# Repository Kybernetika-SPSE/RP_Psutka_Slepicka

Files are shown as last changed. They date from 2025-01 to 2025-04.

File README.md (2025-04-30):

# Dílčí vypracovnání
[here](škola_info)
---

# 🛰️ Lokalizační systém na dvoupásovém vozidle pomocí ESP32, UWB a Wi-Fi

Tato ročníková práce představuje hybridní lokalizační systém postavený na platformě ESP32, který je integrován do dvoupásového robotického vozidla. Systém využívá **Ultra-Wideband (UWB)** pro přesné měření vzdáleností a **Wi-Fi fingerprinting** pro přibližnou lokalizaci. ESP32 zároveň umožňuje řízení vozidla nebo může fungovat jako samostatný **navigační modul** připojený přes Serial k jinému mikrokontroléru.

## ⚙️ Hlavní funkce

- 🚗 **Mobilní platforma:** ESP32 je umístěno na dvoupásovém vozidle a může jej samostatně ovládat.
- 🔁 **Modulární režim:** ESP32 lze přepnout do režimu **navigačního modulu** a komunikovat s jiným mikrokontrolérem přes sériovou linku.
- 📡 **UWB lokalizace:** Využívá se knihovna [`thotro/arduino-dw1000`](https://github.com/thotro/arduino-dw1000) pro přesné měření vzdáleností.
- 📶 **Wi-Fi fingerprinting:** ESP32 detekuje okolní Wi-Fi sítě a odhaduje polohu v neznámém prostředí.
- 🌐 **Webové rozhraní:** ESP32 hostuje jednoduchý web s informacemi o aktuální poloze.
- 🐍 **Python vizualizace:** V reálném čase je možné zobrazit pozici vozidla pomocí animace v Pythonu (`matplotlib`).
- 🔌 **Serial komunikace:** ESP32 odesílá výstupy polohy přes Serial — buď do počítače, nebo do jiného MCU.

## 📁 Struktura projektu

```
RP_Psutka_Slepicka/
├── PCB/                     # KiCad soubory pro návrh desky plošných spojů
├── modely/                  # 3D modely pro tisk
├── škola_info/              # Dílčí vypracování
├── docs/                    # Fotodokumentace
├── src/
│   ├── main/
│   │   ├── data/
│   │   │   ├── *.html       # Webové stránky hostované ESP32
│   │   │   └── *.json       # Hesla k Wi-Fi, uložené Wi-Fi fingerprinty
│   │   └── src/             # Zdrojový kód pro hlavní firmware ESP32
│   └── wifi-scan/           # ESP32 projekt pro sběr Wi-Fi fingerprintů
```

## 🧰 Použité technologie

- **ESP32-DevKitC v4**
- **DWM1000 UWB moduly**
- **PlatformIO + Arduino framework**
- **Python + matplotlib**
- **HTML + JavaScript (web na ESP32)**

## 🔧 Režimy provozu

### 🚘 Autonomní režim
ESP32 ovládá motorové jednotky vozidla a využívá lokalizaci pro navigaci.

### 🔗 Navigační modul
ESP32 funguje jako lokalizační jednotka připojená k jinému mikrokontroléru (např. další ESP32 nebo Arduino). Odhadovaná pozice je pravidelně posílána přes Serial.

## 💬 Komunikace po Serialu

Formát výstupu:
```
POS:[x,y] (2D) nebo POS:[x,y,z] (3D)
```

Možné rozšíření o příkazy pro změnu režimu, kalibraci, atd.

## 📸 Ukázky

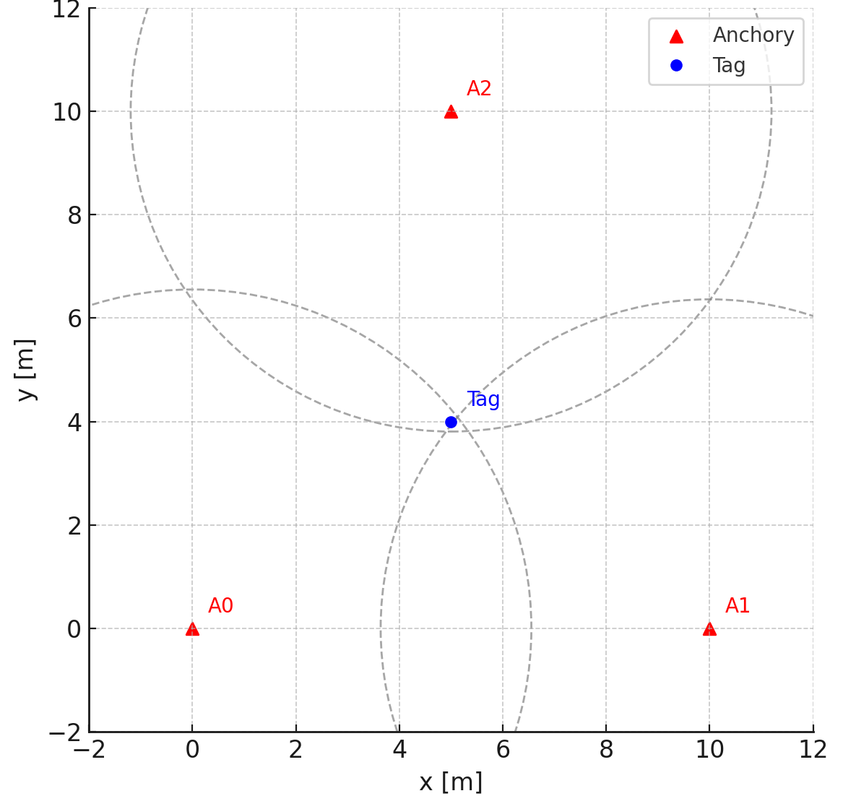
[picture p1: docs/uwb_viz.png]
UWB simulace


## 📚 Zdroje

- [DW1000 datasheet](https://thetoolchain.com/mirror/dw1000/dw1000_user_manual_v2.05.pdf)
- [UWB localization – Wikipedia](https://en.wikipedia.org/wiki/Real-time_locating_system)
- [Arduino-DW1000 GitHub repo](https://github.com/thotro/arduino-dw1000)

## 📄 Licence

Projekt je vytvořen jako ročníková práce a není určen pro komerční použití.

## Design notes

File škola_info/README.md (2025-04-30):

# Dílčí vypracovnání

## Psutka
[zadání](RP_Zadání_Psutka.pdf)

[dokumentace](docs/Psutka/)

+ [Prosinec](reporty/Psutka/2024_12_20.pdf)
+ [Leden](reporty/Psutka/2025_1_31.pdf)
+ [Únor](reporty/Psutka/2025_2_28.pdf)
+ [Březen](reporty/Psutka/2025_3_28.pdf)

## Slepička
[zadání](RP_Zadání_Slepička.pdf)

[dokumentace](docs/Slepička/)

+ [Prosinec](reporty/Slepička/2024_12_20.pdf)
+ [Leden](reporty/Slepička/2025_1_31.pdf)
+ [Únor](reporty/Slepička/2025_2_28.pdf)
+ [Březen](reporty/Slepička/2025_3_28.pdf)

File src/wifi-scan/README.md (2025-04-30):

# Funkce wifi-scan

Tento projekt poskytuje nástroje pro skenování dostupných WiFi sítí pomocí ESP32 a jejich následné zpracování.

## Použití

1. Připojte ESP32 k počítači.
2. Spusťte `scan.py` pro inicializaci skenování.
3. Zadejte název a lokaci pro každé skenování.
4. Data budou uložena do `scanData/networks_raw.json`.
5. Spusťte `format.py` pro formátování dat do `scanData/networks.json`.

## Struktura souborů

- `scan.py`: Skript pro skenování WiFi sítí a ukládání dat.
- `format.py`: Skript pro formátování naskenovaných dat.
- `scanData/`: Složka obsahující naskenovaná data.
- `src/`: Zdrojové kódy pro ESP32.

## Poznámky

- Tento projekt vyžaduje knihovnu `pyserial` pro komunikaci s ESP32. Nainstalujte ji pomocí `pip install pyserial`.
- Ujistěte se, že ESP32 má potřebná oprávnění pro přístup k sériovému portu.
- Pravidelně zálohujte data skenování, abyste předešli jejich ztrátě.

Pro více informací se odkažte na hlavní dokumentaci projektu.

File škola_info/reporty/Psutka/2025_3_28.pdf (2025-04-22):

# RP report

Matěj Psutka

28.3.2025

Během tohoto měsíce jsem dokoupil všechny zbývající součástky potřebné k dokončení projektu. Některé z nich již dorazily, zatímco zbytek očekávám v průběhu příštího týdne. Jakmile budou všechny komponenty k dispozici, začne proces pájení a sestavování celého systému.

Zakoupené součástky:

- Spínače
- 3x Baterie 3.7V
- Balancer na baterie
- Socket na 3 baterie
- Nabíjecí modul 12.5V
- H-můstek 5A 3-14V
- Stepdown modul 6-32V na 5V
- 2x N20 Mini micro metal gear motor 6V 500RPM
- 2x Pogo 2pin
- 2x Pogo 4pin
- 4x Pogo 5pin

Některé z našich webových stránek jsem některé z nich lehce poupravil. CSS styl jsem přepsal do vlastního souboru který se dá jednoduše upravovat, což zjednodušuje tvorbu stránek.

Začal jsem se učit s knihovnou Pygame s cílem vytvořit přehledné grafické prostředí pro ovládání Auta. V tuto chvíli se pouze zaměřuji na základy.

1

Také jsem vytvořil schéma zapojení elektroniky pro autíčko. Toto schéma slouží jako základ pro propojení jednotlivých komponent a usnadní sestavení celého systému.

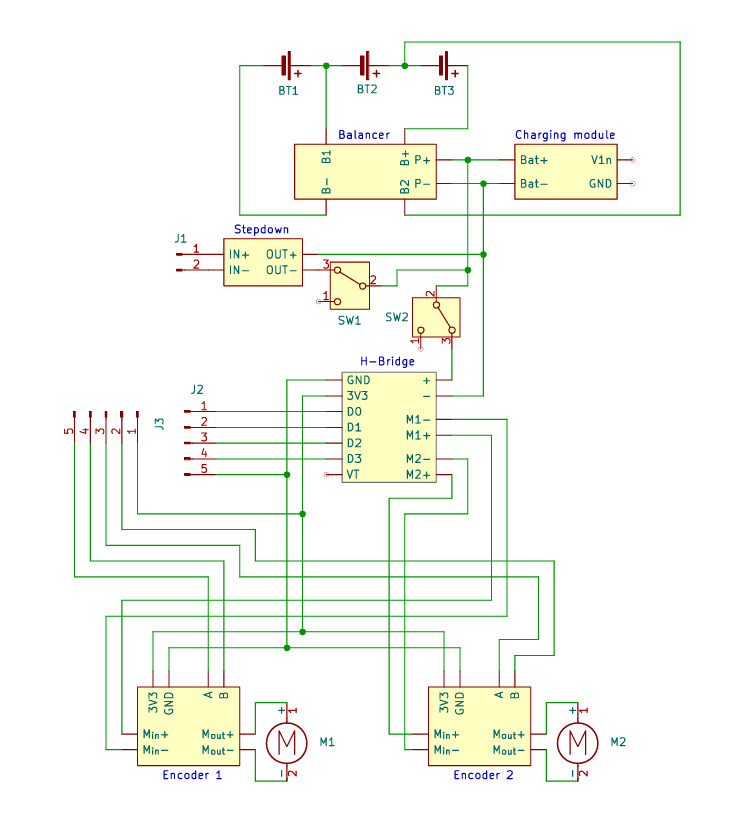
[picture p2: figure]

2

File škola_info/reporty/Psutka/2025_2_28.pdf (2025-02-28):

# RP report

Matěj Psutka

28.2.2025

Tenhle měsíc jsem dodělal finální verze modelu krabičky na čip s vývody na 3 LED a několik děr na pogo piny které se nakonec magneticky připojí ke zbytku auta. Plán je že máme malou krabičku ve které bude většina komponentů a půjde nastavit jedním tlačítkem zda se bude chovat jako maják a nebo jako auto. V případě majáku tak postačí a u auta tak se tato malá krabička připojí pomocí magnetů k větší krabičce ve které budou motory a celý zbytek auta.

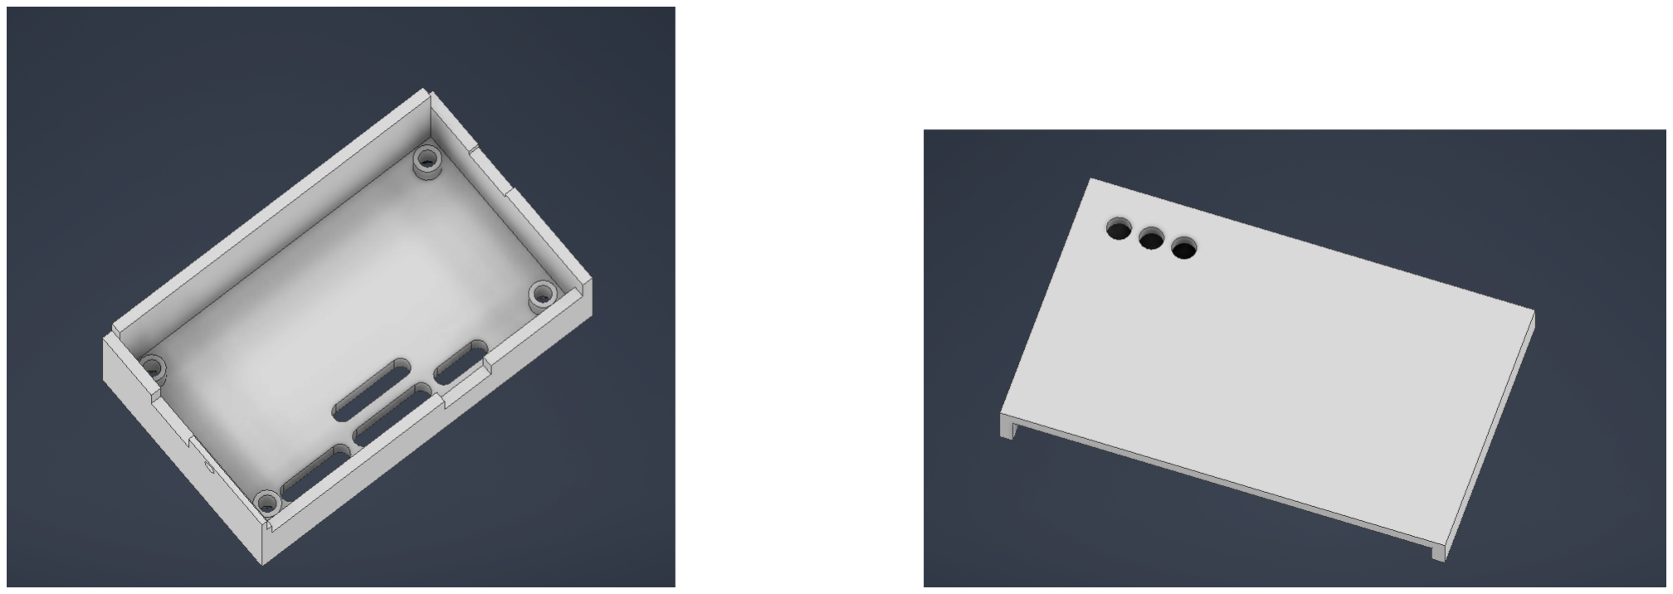
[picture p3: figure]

Spodní část | Horní část

1

Také jsem udělal HTML stránku která vypíše naskenované wifi z ESP (data vezme z JSON souboru). Stránka také ukazuje jak je wifi zaheslovaná a jakou má sílu připojení pomocí obrázku nalevo od názvu. Vpravo je tlačítko které otevře vyskakovací okno s místem na heslo.

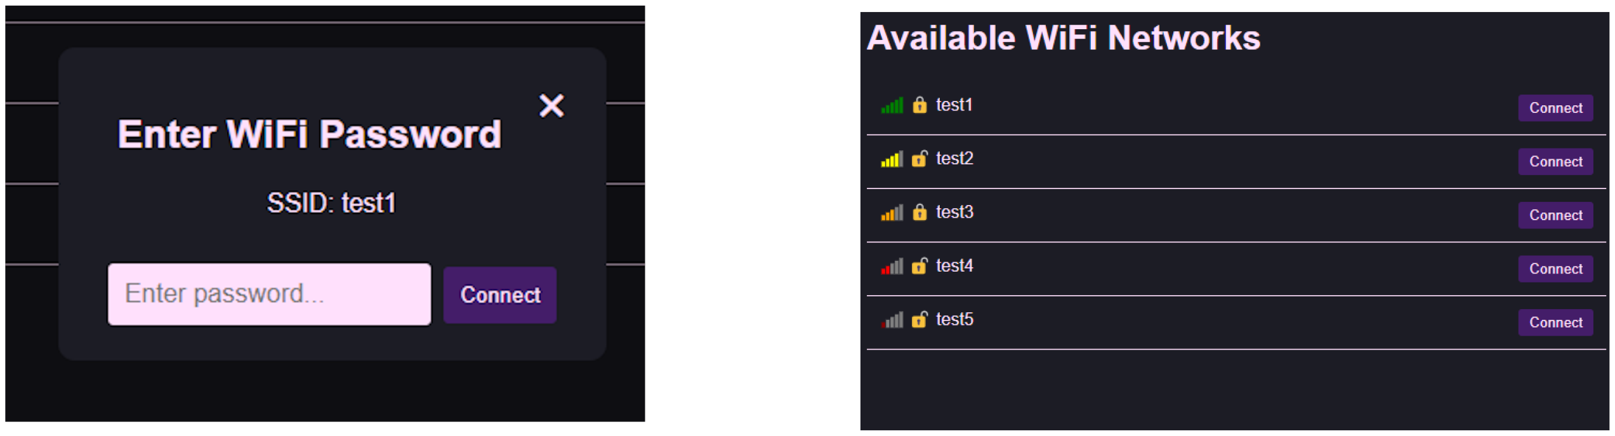
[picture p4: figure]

Vyskakovací okno | Stránka na připojování

K předchozí stránce jsem ještě vytvořil hlavní menu které bude v budoucnu odkazovat na ostatní stránky.

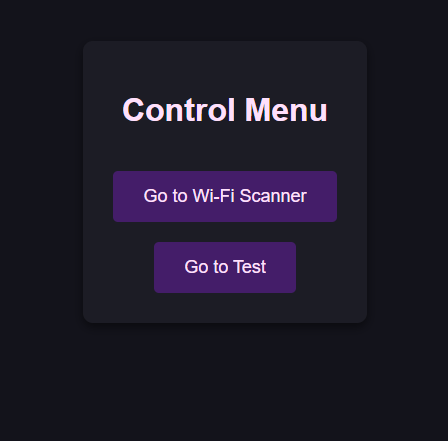
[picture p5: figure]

Hlavní menu

2

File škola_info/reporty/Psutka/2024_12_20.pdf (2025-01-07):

# RP report

Matˇej Psutka

20.12.2024

Naˇsli jsme si souˇc´astky potˇrebn´e k sestrojen´ı z´akladn´ıho modelu Objednali jsme:

- 2x DWM1000 UWB positioning adapter
- 2x DWM1000
- 2x ESP32 developmet board
- 3.7V Lithium battery charger

1

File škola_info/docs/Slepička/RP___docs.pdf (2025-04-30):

## Vyšší odborná škola a Strední pr˚umyslová škola elektrotechnická, ˇ Plzen, Koterovská 85 ˇ

## ROCNÍKOVÁ PRÁCE S OBHAJOBOU ˇ

Téma: | Navigacní systém ˇ
| pomocí UWB
Autor práce: | František Slepicka ˇ
Tˇrída: | 3.M
Vedoucí práce: | Jiˇrí Švihla
Dne: | 30.4.2025

## Hodnocení:

## Anotace

Tato práce se zabývá návrhem a realizací hybridního lokalizacního systému, který kombinuje ˇ
dve technologie – Ultra-Wideband (UWB) pro p ˇ | | ˇresné meˇˇrení vzdálenosti a Wi-Fi fingerprinting
pro orientacní ur ˇ | cení polohy. P ˇ | ˇri známém pohybu jednoho zaˇrízení v prostoru je systém schopen
urcit polohu druhého za ˇ | | ˇrízení. Ovládání je možné prostˇrednictvím webového rozhraní nebo
sériové komunikace. Výsledný systém je navržen pro snadnou integraci do dalších projekt˚u, a to bud’ jako hlavní ˇrídicí jednotka, nebo jako rozšiˇrující lokalizacní modul. ˇ
M˚uj kolega se podílel na projektu zejména v techto oblastech: vytvo ˇ | ˇril webové stránky pro
ovládání systému, navrhl design vozidla a ochranných krabicek pro elektroniku, a fyzicky osadil ˇ a pájel desky plošných spoj˚u.

„Prohlašuji, že jsem tuto práci vypracoval samostatne a použil literárních pramen˚u a informací, ˇ které cituji a uvádím v seznamu použité literatury a zdroj˚u informací.“

„Prohlašuj, že jsem nástroje UI využil v souladu s principy akademické integrity a že na využití techto nástroj˚u v práci vhodným zp˚usobem odkazuji.“ ˇ

„Souhlasím s využitím mé práce uciteli VOŠ a SPŠE Plze ˇ | n k výuce.“ ˇ
V Plzni dne: | Podpis:

## Obsah

Úvod | 5
1 Teoretický základ lokalizace | 6
2 Návrh hybridního systému | 9
3 Realizace systému | 10
4 Testování a vyhodnocení | 19
Záverˇ | 20
Seznam príloh ˇ | 22

## Úvod

V posledních letech roste potˇreba pˇresné a spolehlivé lokalizace objekt˚u nejen ve venkovním prostˇredí pomocí systém˚u jako je GPS, ale také v interiéru, kde tyto technologie ztrácejí na spolehlivosti. Téma lokalizacních systém˚u je tedy stále aktuální, a to zejména s ohledem na rozvoj ˇ robotiky, chytrých zaˇrízení a automatizace. Z tohoto d˚uvodu jsem se rozhodl vytvoˇrit vlastní
hybridní lokalizacní systém, který kombinuje dv ˇ | e odlišné technologie – UWB, známou pro ˇ
svou vysokou pˇresnost meˇˇrení vzdálenosti, a Wi-Fi fingerprinting, který umožnuje orienta ˇ | cní ˇ
urcení polohy i bez p ˇ | ˇrímé viditelnosti mezi zaˇrízeními.
Cílem této práce je navrhnout a realizovat funkcní lokaliza ˇ | cní systém, který dokáže ur ˇ | cit polohu ˇ
zaˇrízení v prostoru s využitím obou výše zmínených metod. Výsledný systém má být snadno ˇ použitelný, rozšiˇritelný a vhodný pro integraci do dalších projekt˚u – napˇríklad jako hlavní ˇrídicí
jednotka mobilního robota nebo jako doplnkový lokaliza ˇ | cní modul. ˇ

Pˇri návrhu a realizaci byly využity dostupné mikrokontroléry ESP32, pˇricemž komunikace a ˇ
ovládání systému probíhá bud’ pˇres webové rozhraní, nebo sériove. Teoretická ˇ | cást práce se ˇ
venuje princip˚um obou použitých lokaliza ˇ | cních metod a shrnuje jejich výhody i omezení. Prak- ˇ
tická cást se zam ˇ | eˇˇruje na implementaci systému, komunikaci mezi moduly a vizualizaci vý-
sledk˚u.

Pˇrínosem této práce je vytvoˇrení flexibilního a otevˇreného ˇrešení, které m˚uže posloužit jako základ pro další rozvoj lokalizacních systém˚u v hobby i profesionálních aplikacích. ˇ

## 1 Teoretický základ lokalizace

### 1.1 Prehled metod lokalizace a jejich srovnání ˇ

Lokalizace objekt˚u v prostoru je v soucasnosti d˚uležit ˇ | ejší než kdy d ˇ | ˇríve – a to zejména díky
rozvoji autonomních systém˚u v oblasti automatizace, dopravy a osobní elektroniky. S rostoucími nároky na pˇresnost, rychlost a univerzálnost lokalizacních systém˚u vzniklo mnoho r˚uzných ˇ pˇrístup˚u k ˇrešení tohoto problému.

Jedním z pˇrístup˚u je využití computer vision (CV) a lidaru – technologií, které se nejvíce pˇribližují lidskému zp˚usobu vnímání prostoru. Pomocí neuronových sítí lze z obrazových dat z kamer, pˇrípadne z pointcloudu získaného lidarem, odhadnout vlastní polohu i polohu okolních ˇ
objekt˚u. Nicméne,tyto metody vyžadují zna ˇ | cný výpo ˇ | cetní výkon, kvalitní senzory a rozsáhlá ˇ
trénovací data, což m˚uže zvyšovat náklady a složitost implementace. Nejcast ˇ | eji se uplat ˇ | nují v ˇ
automobilovém pr˚umyslu nebo v pokrocilé robotice. ˇ
Global Positioning System (GPS) je nejrozšíˇrenejší lokaliza ˇ | cní systém. Je snadno implemen- ˇ
tovatelný a cenove dostupný, což z n ˇ | ejˇ ciní populární volbu v mobilních telefonech a automo- ˇ
bilech. Avšak v interiérových prostˇredích je jeho využití omezené kv˚uli slabému nebo žádnému
signálu ze satelit˚u, což zp˚usobuje nízkou pˇresnost nebo úplnou nefunkcnost systému. P ˇ | ˇresnost
se obvykle pohybuje mezi 5 až 10 metry.

Další metodou využívanou pˇredevším v interiérovém prostˇredí je Wi-Fi fingerprinting. Tato
technika využívá meˇˇrení síly signálu (RSSI) z nekolika Wi-Fi p ˇ | ˇrístupových bod˚u a porovnává
je s databází známých meˇˇrení (tzv. otisk˚u, fingerprints), která byla pˇredem nasbírána v daném
prostoru. Lokalizace pak spocívá v nalezení nejbližší shody mezi aktuálním m ˇ | eˇˇrením a databází.
Výhodou této metody je relativne nízká cena a možnost použití b ˇ | ežného Wi-Fi hardwaru bez ˇ
nutnosti pˇrímé viditelnosti. Nevýhodou je nutnost pˇredchozího podrobného mapování prostoru
a náchylnost na zmeny prost ˇ | ˇredí (napˇr. nové pˇrekážky nebo zmeny v síti), které mohou snížit ˇ
pˇresnost. Typická pˇresnost se pohybuje mezi 2 až 4 metry.

Další možností je meˇˇrení síly signálu – napˇríklad pomocí indikátoru Received Signal Strength Indicator (RSSI). Tento pˇrístup je jednoduchý, levný a nevyžaduje speciální hardware. Vzdá-
lenost lze odhadnout z útlumu signálu – cím dál je p ˇ | ˇrijímac od vysíla ˇ | ce, tím nižší je RSSI. ˇ
Pˇresnost této metody se pohybuje mezi 2 až 4 metry za ideálních podmínek, ale m˚uže být ovliv-
nena rušením, odrazy signálu a dalšími faktory prost ˇ | ˇredí, což snižuje její spolehlivost.

Zcela odlišný princip využívá Ultra-Wideband (UWB), který místo síly signálu meˇˇrí cas letu ˇ
(Time of Flight, ToF). Díky tomu je možné urcit vzdálenost s p ˇ | ˇresností v ˇrádu desítek centime-
tr˚u. Její dosah je omezen na desítky metr˚u a vyžaduje pˇrímou viditelnost mezi zaˇrízeními pro optimální výkon. I když jsou náklady na implementaci vyšší než u jiných metod, UWB nabízí vynikající pˇresnost a je vhodná pro aplikace, kde je klícová precizní lokalizace. ˇ

Tabulka 1: Porovnání lokalizacních metod ˇ
Metoda | Presnost [m] ˇ | Náklady | Typické použití
GPS | 5,0–10,0 | nízké | navigace, venkovní lokalizace
Wi-Fi fingerprinting | 2,0–4,0 | nízké | vnitˇrní lokalizace, IoT
RSSI (Wi-Fi/BLE) | 3,0–5,0 | nízké | jednoduché sledování aktiv
UWB (ToF) | 0,1–0,3 | vyšší | robotika, pˇresné sledování
Computer Vision | <1,0 | vysoké | autonomní vozidla, robotika
Lidar | <0,1 | velmi vysoké | autonomní systémy, mapování

Každá z popsaných metod má své výhody i nevýhody a hodí se pro jiný typ aplikace. GPS je ideální pro venkovní lokalizaci díky širokému pokrytí a nízké cene, ale v interiéru selhává. ˇ Computer vision a lidar nabízejí velmi pˇresnou prostorovou orientaci, avšak za cenu vyso-
kých výpocetních nárok˚u a složité implementace. ˇ | Meˇrení síly signálu (RSSI) ˇ | je jednoduché
a levné, ale znacnˇ e nep ˇ | ˇresné a nespolehlivé v promenlivém prost ˇ | ˇredí. Wi-Fi fingerprinting
tento pˇrístup vylepšuje pomocí databáze meˇˇrení, ale vyžaduje rozsáhlou kalibraci a je náchylný
na zmeny v prostoru. ˇ | UWB naopak poskytuje velmi pˇresné meˇˇrení vzdálenosti, ale vyžaduje
pˇrímou viditelnost a má omezený dosah.

Kombinace Wi-Fi a UWB se proto jeví jako ideální kompromis – Wi-Fi fingerprinting po-
krývá vetší prostor a umož ˇ | nuje rychlou hrubou lokalizaci bez nutnosti p ˇ | ˇrímé viditelnosti, za-
tímco UWB umožní v pˇrípade pot ˇ | ˇreby zpˇresnení polohy na decimetrovou úrove ˇ | n v okolí ak- ˇ
tivních kotvených bod˚u. Vzájemným propojením obou metod lze dosáhnout vyšší pˇresnosti, robustnosti a univerzálnosti celého systému, což je zvlášte výhodné pro mobilní roboty nebo ˇ zaˇrízení pohybující se v dynamickém interiérovém prostˇredí.

### 1.2 Existující lokalizacní systémy ˇ

V pˇredchozí cásti byly popsány základní principy lokaliza ˇ | cních metod. V této kapitole budou ˇ
na tyto principy navázány konkrétní systémy, které je implementují v praxi. Jedná se o reálná ˇrešení využívaná v r˚uzných oblastech – od osobní elektroniky pˇres automobilový pr˚umysl až
po pr˚umyslové a vedecké aplikace. Srovnáním t ˇ | echto systém˚u lze lépe porozum ˇ | et výhodám a ˇ
omezením jednotlivých pˇrístup˚u v reálném nasazení.

Global Positioning System (GPS) je soucástí tzv. Global Navigation Satellite Systems (GNSS) ˇ
– celosvetových systém˚u pro ur ˇ | cování polohy pomocí družic. Krom ˇ | e amerického GPS existuje ˇ
napˇríklad ruský GLONASS, evropské Galileo nebo cínské BeiDou. Je to nejrozší ˇ | ˇrenejší me- ˇ
toda pro lokalizaci ve venkovních prostorech. Systém využívá signály z družic, pomocí kterých
zaˇrízení urcuje svoji polohu. P ˇ | ˇresnost se pohybuje mezi 5–10 m, v nekterých p ˇ | ˇrípadech až pod

1 m pˇri použití korekcních služeb (nap ˇ | ˇr. RTK). Používá se v telefonech, navigacích, dronech i
autech.

Wi-Fi fingerprinting – Google Location Services používají obrovskou databázi známých Wi-
Fi sítí (jejich SSID, BSSID a RSSI hodnoty) ke zpˇresnení lokalizace za ˇ | ˇrízení, zvlášte v místech ˇ
bez GNSS signálu. Tato technologie je základem lokalizace v interiéru u vetšiny Android za ˇ | ˇrí-
zení. Pˇresnost m˚uže být mezi 5–15 m v závislosti na hustote p ˇ ˇrístupových bod˚u.

Bluetooth Low Energy (BLE) beacony – Apple iBeacon, Eddystone jsou systémy, které vy-
sílají krátké identifikátory, které zaˇrízení pˇrijímají a využívají k urcení polohy. Používá se ˇ | casto ˇ
v muzeích, obchodech nebo chytrých budovách. Pˇresnost je vetšinou v rozmezí 1–5 m. Výho- ˇ dou je nízká spotˇreba energie a nízké náklady, nevýhodou je nutnost velkého poctu beacon˚u pro ˇ vyšší pˇresnost.

Ultra-Wideband (UWB) – Apple AirTag, Qorvo, Sewio využívají moderní technologie UWB
umožnující velmi p ˇ | ˇresnou lokalizaci pomocí meˇˇrení casu letu signálu (ToF). AirTag od Applu ˇ
používá UWB pro lokalizaci v rámci systému „Find My“, kde je možné pˇresne ur ˇ | cit sm ˇ | er a ˇ
vzdálenost ztraceného zaˇrízení. Pr˚umyslové systémy jako Qorvo nebo Sewio nabízejí ˇrešení pro lokalizaci s pˇresností pod 30 cm, casto používaná v logistice, skladech nebo výrobních ˇ halách.

Vizuální lokalizace – Google ARCore a Apple ARKit jsou systémy využívající kamery a al-
goritmy pro simultánní lokalizaci a mapování (SLAM), aby urcily pozici za ˇ | ˇrízení v prostoru.
Používají se napˇríklad v rozšíˇrené realite nebo autonomní robotice. Výhodou je možnost fun- ˇ
gování bez externích senzor˚u, ale je potˇreba výpocetn ˇ | e náro ˇ | cný hardware. ˇ

## 2 Návrh hybridního systému

### 2.1 Kombinace UWB a Wi-Fi – d˚uvody a výhody

Wi-Fi a UWB v tomto systému nefungují jako propojené metody, ale jako dve nezávislé vrstvy ˇ
lokalizace, které se navzájem doplnují. Zatímco Wi-Fi fingerprinting poskytuje p ˇ | ˇribližnou ori-
entaci v prostoru – napˇríklad urcení aktuální místnosti ˇ | ci zóny – UWB slouží k p ˇ | ˇresnému meˇˇrení
vzdálenosti mezi dvema za ˇ | ˇrízeními.
Tato kombinace umožnuje p ˇ | ˇrizp˚usobit úroven p ˇ ˇresnosti konkrétní situaci. Napˇríklad pˇri ztráteˇ
pˇrímé viditelnosti pro UWB m˚uže hrubá Wi-Fi poloha stále poskytnout základní informaci o poloze. Naopak v pˇrípadech, kde je potˇreba centimetrová pˇresnost, se využije pohyb navigacního ˇ zaˇrízení a sekvence UWB meˇˇrení k odhadu pˇresné polohy cílového tagu pomocí trilaterace.
Díky této dvouvrstvé architektuˇre lze systém použít i v r˚uznorodých a promenlivých prost ˇ | ˇre-
dích, kde není k dispozici stabilní podmínky pro jednu konkrétní metodu lokalizace.

### 2.2 Cílové použití a požadavky na systém

Navržený lokalizacní systém je ur ˇ | cen pro použití v interiérovém prost ˇ | ˇredí, kde není dostupná
pˇresná satelitní navigace. Pˇredpokládá se nasazení napˇríklad v budovách, školách nebo skla-
dech, kde je k dispozici stabilní Wi-Fi infrastruktura a zároven existuje pot ˇ | ˇreba lokalizace mo-
bilních zaˇrízení ci vozidel s vyšší p ˇ | ˇresností.
Systém by mel být jednoduchý na použití a snadno rozší ˇ | | ˇritelný do dalších projekt˚u. Mel by ˇ
být schopen pomocí Wi-Fi fingerprintingu rozlišit jednotlivé cásti prostoru, vypsat vzdálenost ˇ
k druhému UWB zaˇrízení a pˇri pohybu navigátoru použít trilateraci k urcení jeho p ˇ | ˇresné po-
lohy. Výsledky lokalizace by mely být p ˇ | ˇrístupné skrze webové rozhraní a pˇripravené k dalšímu
zpracování ci vizualizaci. ˇ

## 3 Realizace systému

### 3.1 Použitý hardware

Pro vytvoˇrení funkcního lokaliza ˇ | cního systému bylo nejprve nutné zvolit vhodné hardwarové ˇ
komponenty a navrhnout vlastní desku plošných spoj˚u pro jejich propojení. Cílem bylo dosáhnout kompaktního, pˇrehledného a snadno rozšiˇritelného ˇrešení, které umožní spolehlivý provoz jak Wi-Fi fingerprintingu, tak pˇresného UWB meˇˇrení vzdáleností.

### 3.1.1 ESP32

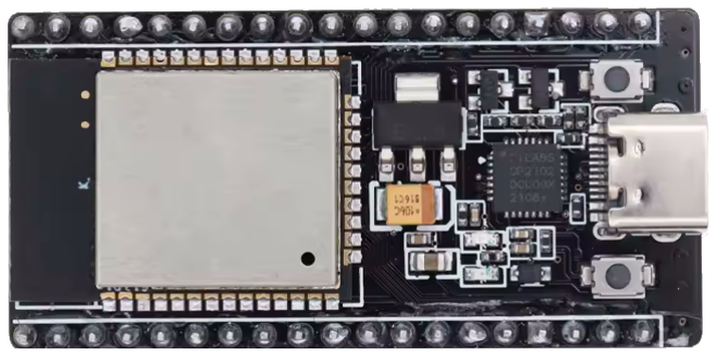
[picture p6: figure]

Obrázek 1: ESP32 DevKitC [zdroj: vlastní]

Pro tento projekt bylo zvoleno vývojové prostˇredí ESP32 [3] díky jeho široké dostupnosti a
bežnému použití v oblasti IoT. Klí ˇ | covými vlastnostmi, které rozhodly o jeho nasazení, byly ˇ
vestavený Wi-Fi modul a dostate ˇ | cnˇ e výkonná dvoujádrová architektura. ˇ

Použitým modelem je ESP32 DevKitC (viz Obrázek 1).

V rámci projektu ESP32 zajišt’uje:

- provádení UWB rangingu, ˇ
- skenování dostupných Wi-Fi sítí,
- provoz webového serveru,
- výpocty pro trilateraci. ˇ

Použité periferie:

- UART – komunikace s pˇripojenými zaˇrízeními,
- SPI – spojení s UWB modulem,
- GPIO – ovládání stavové LED a možnost pˇripojení dalších externích prvk˚u,
- I

2C – rezervováno pro pˇrípadné rozšíˇrení o další senzory (v aktuální verzi nejsou využity).

### 3.1.2 UWB modul

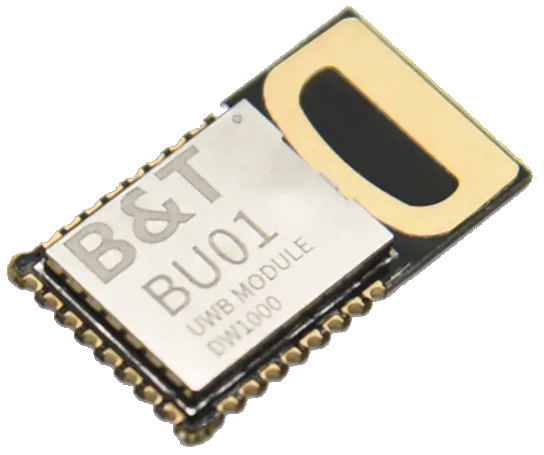
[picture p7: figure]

Obrázek 2: UWB modul BU01 [zdroj: vlastní]

Pro realizaci systému byl použit UWB modul BU01 (Obrázek 2), který je založen na cipu ˇ DW1000 [2] od spolecnosti Decawave. ˇ

Modul umožnuje p ˇ | ˇresné meˇˇrení vzdáleností pomocí metody obousmerného ˇ | casového m ˇ | eˇˇrení
(Two-Way Ranging, ToF) s pˇresností až 10 cm. Podporuje pˇrenosové rychlosti až 6,8 Mbps a je vhodný pro real-time lokalizacní aplikace v interiéru. ˇ

V projektu je modul pˇripojen k PCB pomocí adaptérové desky, která umožnuje jednoduché ˇ propojení pˇres sbernici SPI. ˇ

### 3.1.3 Návrh a výroba PCB

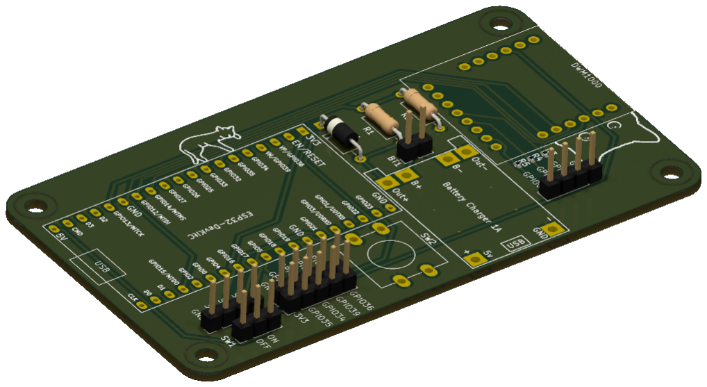
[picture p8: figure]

Obrázek 3: PCB [zdroj: vlastní]

Pro tvorbu vlastní desky plošných spoj˚u (PCB) jsem se rozhodl kv˚uli pˇrehlednosti zapojení, sní-
žení celkových rozmer˚u, pot ˇ | ˇrebe p ˇ ˇripojit napájecí modul a UWB modul, vlastnímu vyzkoušení
návrhu PCB a také kv˚uli jistote správného propojení všech sou ˇ | cástek. ˇ

Schéma zapojení i návrh samotné desky jsem vytvoˇril v programu KiCAD [5]. Výroba desky
probehla u spole ˇ | cnosti JLCPCB. ˇ

Na desce (Obrázek 3) se nachází:

- ESP32 DevKitC,
- UWB modul BU01,
- nabíjecí modul TP4056,
- rezistory s diodou pro meˇˇrení stavu baterie,
- vypínac pro odpojení napájení, ˇ
- pˇríprava pro tlacítko (na finální desce není osazeno), ˇ
- vývody pro stavové LED diody s pˇríslušnými rezistory (indikace stavu UWB),
- konektor pro pˇripojení baterie,
- dvakrát GND, dvakrát 3V3 a desetkrát volne p ˇ ˇrístupných GPIO pin˚u.

### 3.2 Softwareová implementace

Po návrhu a sestavení hardwarové cásti systému bylo nutné vytvo ˇ | ˇrit odpovídající softwarové
vybavení. Programové vybavení ˇrídí sber dat, komunikaci a výpo ˇ | cty a prezentaci výsledk˚u ce- ˇ
lého systému.
Software je rozdelen do dvou hlavních ˇ | cástí: ˇ
- program bežící na mikrokontroléru ESP32, napsaný v C++ [ ˇ | 4] s využitím platformy Ar-
duino [1],
- podp˚urné skripty bežící na po ˇ | cíta ˇ ci, napsané v Pythonu [ ˇ | 6].
ESP32 zajišt’uje meˇˇrení vzdáleností, správu webového rozhraní, sber Wi-Fi dat a lokaliza ˇ | cní ˇ
výpocty. ˇ | Skripty v jazyce python slouží pro sber a p ˇ | ˇrípravu fingerprintingových dat.
Softwarová architektura se delí na následující hlavní ˇ | cásti: ˇ
- správa webového rozhraní pro pˇrístup k dat˚um a ovládání systému,
- skenování Wi-Fi sítí pro potˇreby fingerprintingu,
- meˇˇrení vzdáleností pomocí technologie UWB,

- trilaterace a výpocet p ˇ | ˇresné polohy cílového zaˇrízení.
V následujících podkapitolách jsou jednotlivé cásti popsány podrobn ˇ | eji. ˇ

### 3.2.1 Webové rozhraní

Webové rozhraní slouží k jednoduchému ovládání systému a zobrazení všech d˚uležitých dat
bez nutnosti fyzického pˇripojení k zaˇrízení. To je zvlášte užite ˇ | cné v p ˇ | ˇrípade, kdy je za ˇ | ˇrízení
pˇripevneno na pohyblivé platform ˇ | e.ˇ
Webserver beží p ˇ | ˇrímo na ESP32 díky vestavenému Wi-Fi modulu. Není tedy pot ˇ | ˇreba žádné
další zaˇrízení, které zprostˇredkovává web, avšak je nutné znát IP adresu ESP32.

Pˇripojení k webserveru probíhá tak, že se ESP32 pˇripojí k existující Wi-Fi síti (nebo vytvoˇrí vlastní pˇrístupový bod), a po zadání jeho IP adresy do webového prohlížece se uživatel dostane ˇ na hlavní ovládací panel.

Jednotlivé stránky webového rozhraní jsou tvoˇreny pomocí HTML, CSS a JavaScriptu. Stránky
jsou zámern ˇ e co nejjednodušší, aby zabíraly minimum pam ˇ | eti a byly rychlé i na omezeném ˇ
hardwaru ESP32.
Webové rozhraní je rozdeleno do n ˇ | ekolika ˇ | cástí: ˇ
- index.html – hlavní stránka s odkazy na ostatní cásti webového rozhraní, ˇ
- wifi_connection.html – správa pˇripojení k Wi-Fi sítím,
- location.html – zobrazení aktuální polohy získané pomocí Wi-Fi fingerprintingu,
- UWB.html – zobrazování vzdálenosti a ovládání meˇˇrení pomocí UWB.

### 3.2.2 Lokalizace pomocí Wi-Fi fingerprintingu

Skenování Wi-Fi sítí je klícovým krokem pro vytvo ˇ | ˇrení databáze otisk˚u míst (fingerprint˚u) zalo-
žených na dostupných sítích a jejich síle signálu. Z této databáze lze následne zp ˇ | etn ˇ e odhadovat ˇ
pˇribližnou polohu zaˇrízení pouze na základe aktuáln ˇ | e dostupných Wi-Fi sítí. ˇ

Získávání fingerprint˚u probíhá jednoduchým skenováním dostupných Wi-Fi sítí pomocí ESP32. Výsledkem každého skenu je seznam pˇrístupových bod˚u, u kterých známe:

- SSID – název síte (nap ˇ ˇr. „eduroam“),
- BSSID – unikátní identifikátor pˇrístupového bodu (MAC adresa, napˇr. „00-B0-D0-63-C2-26“),

- RSSI – síla pˇrijímaného signálu (v dBm, napˇr. „-76“).
Získaná data jsou odesílána pˇres sériovou linku do pocíta ˇ ce, kde je Python skript ˇ | scan.py ukládá
a pˇriˇrazuje ke každému skenu jméno místa. Výstup je uložen v jednoduchém formátu, vhodném pro další zpracování.
Následne druhý skript ˇ | format.py provádí úpravu naskenovaných dat: filtruje pouze stabilní pˇrí-
stupové body (aby se vyloucily nap ˇ | ˇr. mobilní hotspoty) a pr˚umeruje více m ˇ | eˇˇrení pro dosažení
stabilnejších výsledk˚u. ˇ
Pˇri behu systému lze kdykoli na vyžádání spustit Wi-Fi fingerprinting, b ˇ | ehem kterého ESP32 ˇ
provede nový sken, porovná nameˇˇrené hodnoty s uloženou databází a vrátí název místa, které se nejvíce shoduje s aktuální situací.

### 3.2.3 Meˇrení vzdálenosti pomocí UWB ˇ

UWB technologie umožnuje velmi p ˇ | ˇresné meˇˇrení vzdálenosti díky meˇˇrení casu letu (ToF, ˇ | Time
of Flight) signálu mezi dvema za ˇ | ˇrízeními.

Komunikace mezi ESP32 a UWB modulem probíhá pomocí sbernice SPI. Pro ovládání modulu ˇ využívám knihovnu thotro/arduino-dw1000 [7].

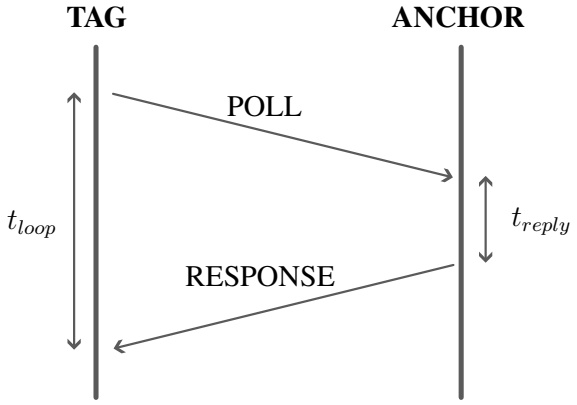
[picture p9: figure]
TAG; ANCHOR; POLL; RESPONSE; tloop; treply

Obrázek 4: Princip meˇˇrení vzdálenosti pomocí UWB [zdroj: vlastní]

Meˇˇrení probíhá tak, že vysílac (tag) vyšle signál ( ˇ | poll), pˇríjímac (anchor) na n ˇ | ej odpoví zprávou, ˇ
ve které je obsažen údaj o case pot ˇ | ˇrebném na odpoved’ ( ˇ | treply). Tag následne zm ˇ | eˇˇrí celkový cas ˇ
od vyslání po pˇrijetí odpovedi ( ˇ | tloop), viz Obrázek 4.
Z techto dvou ˇ | cas˚u lze vypo ˇ | cítat skute ˇ | cný ˇ | cas letu podle vzorce: ˇ

T oF =

tloop − treply
2

Z nameˇˇreného casu ToF se vzdálenost ur ˇ | cí pomocí známé rychlosti ší ˇ | ˇrení signálu (rychlost
svetla). ˇ

Zaˇrízení m˚uže pracovat ve dvou režimech:

- Anchor – ceká na zahájení komunikace, ˇ
- Tag – aktivne odesílá požadavky na m ˇ | eˇˇrení.
Vzdálenost se meˇˇrí opakovane (n ˇ | ekolikrát za sekundu) a výsledky mohou být zpr˚um ˇ | erovány ˇ
pro vyšší stabilitu a eliminaci šumu.

Výstupem je vzdálenost v metrech, která je dále využívána napˇríklad pˇri výpoctu polohy pomocí ˇ trilaterace.

UWB meˇˇrení je velmi pˇresné (bežn ˇ e s odchylkou v jednotkách decimetr˚u), nicmén ˇ | e kvalita ˇ
meˇˇrení výrazne závisí na podmínkách prost ˇ | ˇredí, zejména na pˇrímé viditelnosti mezi zaˇrízeními
(Line of Sight).

### 3.2.4 Trilaterace a výpocet polohy ˇ

Trilaterace [10] je analogie triangulace, která nepracuje s úhly, ale s délkami. Je založena na znalosti vzdáleností od alespon t ˇ ˇrí (ve 2D) nebo cty ˇ ˇr (ve 3D) referencních bod˚u. Tyto body ˇ pˇredstavují statické anchory rozložené v prostoru. V našem pˇrípade se anchor pohybuje a refe- ˇ
rencní body vznikají postupn ˇ | e v ˇ | case, což je dosta ˇ | cující v p ˇ | ˇrípade, že je tag (m ˇ | eˇˇrené zaˇrízení)
statický.

Rovnice kruh˚u (v 2D) nebo koulí (v 3D) je dána vztahem:

(x − xi)

2 + (y − yi)

2 + (z − zi)

2 = d

2
i

,

kde xi

, yi

, zi

jsou souˇradnice anchoru, x, y, z jsou souˇradnice tagu a di je nameˇˇrená vzdálenost.

Tyto rovnice jsou kvadratické. Odectením jedné rovnice od ostatních dojde k eliminaci kvadra- ˇ
tických clen˚u a vznikne soustava lineárních rovnic, kterou lze vyjád ˇ | | ˇrit ve tvaru:
| A⃗x = ⃗b,

kde ⃗x je vektor neznámých souˇradnic (x, y, z).

V reálných scénáˇrích, jako je trilaterace, dochází ke chybám meˇˇrení a nepˇresnostem polohy
referencních bod˚u. Proto soustava ˇ | A⃗x = ⃗b vetšinou nemá p ˇ | ˇresné ˇrešení. Cílem je najít pˇribližné

ˇrešení, které minimalizuje chybu.

Metoda nejmenších ctverc˚u hledá ˇ | ˇrešení, které minimalizuje soucet druhých mocnin odchylek: ˇ

∥

| ⃗b − A⃗x∥
| 2 .

Tím dostaneme normální rovnici:
| A TA⃗x = A T⃗b,

jejíž ˇrešení je dáno vztahem:
| ⃗x = (A TA) −1A T⃗b.
V pˇrípade, že máme k dispozici více než minimální po ˇ | cet vzdáleností (nap ˇ | ˇríklad více než 3
v 2D), umožnuje tato metoda využít redundantní informace pro zp ˇ | | ˇresnení výsledné polohy. ˇ
Stabilita rozmístení referen ˇ | cních bod˚u ˇ | Aby bylo možné správne ur ˇ | cit polohu, je nutné za- ˇ
jistit vhodné rozmístení referen ˇ | cních bod˚u. V p ˇ | ˇrípade, že jsou body kolineární nebo koplanární ˇ
(v 3D), trilaterace není jednoznacnˇ eˇ ˇrešitelná.
Kontrolu kolinearity v 2D provádím pomocí vektorového soucinu. Pokud je vypo ˇ | cítaná plocha ˇ
pˇríliš malá, algoritmus upozorní na nevhodné rozložení bod˚u.
V pˇrípade 3D dat využívám Singular Value Decomposition (SVD) [ ˇ | 9] matice bod˚u:
| | P = UΣV T

kde P je matice obsahující souˇradnice referencních bod˚u. ˇ

Malá hodnota tˇretí singulární hodnoty σ3 oproti σ1 a σ2 indikuje, že body jsou pˇribližne kopla- ˇ nární. Tˇretí sloupec u3 matice U udává normálový vektor roviny, ve které body leží.

Pokud jsou body koplanární, lze trilateraci zjednodušit následovne:ˇ

1. Nalézt rovinu pomocí normálového vektoru u3 a težišt ˇ e bod˚u. ˇ
2. Provést projekci všech bod˚u do této roviny a ˇrešit trilateraci ve zjednodušeném 2D prostoru.
3. Výsledek poté pˇrevést zpet do 3D sou ˇ | ˇradného systému.

Projekce bod˚u do roviny pomocí SVD Pro projekci referencních bod˚u i odhadované polohy ˇ

do roviny využívám výstup SVD.

Nejprve spocítám t ˇ | ežišt ˇ | e všech referen ˇ | cních bod˚u: ˇ

c =

1
n

Xn

i=1

pi

kde pi

jsou souˇradnice jednotlivých bod˚u.

Následne ode ˇ | ctu t ˇ | ežišt ˇ | e od všech bod˚u: ˇ

p

′
i = pi − c

Tím získám souˇradnice relativní k težišti. ˇ

Rovinu, do které se mají body promítnout, urcuji pomocí normálového vektoru ˇ | ⃗n = (a, b, c) a

parametru d z rovnice roviny:
ax + by + cz + d = 0

Pro každý z bod˚u nejprve zjistím jeho vzdálenost od roviny:

λi =

p

′
i
- ⃗n + d
∥⃗n∥

2

a následne ho posunu p ˇ | ˇrímo na rovinu:

pi = p

′
i − λi⃗n
Poté projektuji body do nového souˇradnicového systému urceném prvními dv ˇ | ema sloupci ma- ˇ
tice U:

qi =

"
u1 · pi
u2 · pi

kde qi
je 2D souˇradnice bodu v rovine.ˇ

Tímto zp˚usobem jsou všechny body pˇrevedeny do 2D, kde lze provést klasickou trilateraci.

Po výpoctu polohy ˇ | q v této 2D rovine se výsledek transformuje zp ˇ | et do 3D prostoru: ˇ

p = c +

h
u1 u2

i
q
Tím je zajišteno, že vypo ˇ | ctená poloha respektuje p˚uvodní 3D sou ˇ | ˇradný systém.

Kalman˚uv filtr pro zpresn ˇ | ení polohy ˇ | Pˇri urcování polohy pomocí trilaterace dochází k ná- ˇ
hodným odchylkám zp˚usobeným šumem v meˇˇrených vzdálenostech. K potlacení t ˇ | echto odchy- ˇ
lek a ke zpˇresnení výsledné polohy používám Kalman˚uv filtr [ ˇ | 8].

Kalman˚uv filtr je optimální odhadovací algoritmus pro systémy se šumem, který kombinuje:

- pˇredpoved’ polohy na základ ˇ | | e p ˇ ˇredchozího stavu,
- nové nameˇˇrené hodnoty z trilaterace,
- model nejistoty meˇˇrení a model dynamiky systému.
Filtr iterativne aktualizuje odhadované sou ˇ | | ˇradnice podle rovnic:
- Predikce stavu: ⃗xk|k−1 = Fk⃗xk−1|k−1 + Bkuk
- Predikce kovariancní matice: ˇ | | Pk|k−1 = FkPk−1|k−1F

T
k + Qk
- Výpocet Kalmanova zisku: ˇ | | Kk = Pk|k−1HT
k

(HkPk|k−1HT
k + Rk)

−1

- Aktualizace odhadu: ⃗xk|k = ⃗xk|k−1 + Kky˜k
- Aktualizace kovariancní matice: ˇ | Pk|k = (I − KkHk)Pk|k−1

## 4 Testování a vyhodnocení

### 4.1 Testovací prostredí a postupy ˇ

Testování probíhalo v domácím prostˇredí a ve škole. Pro oveˇˇrení pˇresnosti meˇˇrení jsem postupneˇ posouval tag o známé vzdálenostní pˇrír˚ustky a zaznamenával hodnoty nameˇˇrené lokalizacním ˇ systémem.

Krome reálného testování jsem vytvo ˇ | ˇril také simulacní prost ˇ | ˇredí v Pythonu, kde jsem oveˇˇril
správnost matematických výpoct˚u trilaterace a Kalmanova filtru. Simulace umožnila rychlejší ˇ
ladení algoritm˚u a ov ˇ | eˇˇrení chování systému v ideálních i zarušených podmínkách.
Porovnáním nameˇˇrených dat se skutecnými hodnotami jsem zjistil, že systém bez dodate ˇ | | | cné ˇ
kalibrace nevykazoval dostatecnou p ˇ | ˇresnost. Proto jsem implementoval kalibracní funkci, která ˇ
upravuje hodnoty anténního zpoždení (antenna delay) tak, aby byla výsledná m ˇ | | | eˇˇrená vzdálenost
co nejpˇresnejší. Tento postup výrazn ˇ | e zlepšil shodu mezi reálnou a vypo ˇ | cítanou pozicí. ˇ

### 4.2 Presnost jednotlivých technologií ˇ

Systém využívající technologii UWB dosahoval po kalibraci pˇresnosti meˇˇrení lepší než 10 cm.
Pˇresnost Wi-Fi lokalizace byla výrazne nižší, avšak posta ˇ | covala k ur ˇ | cení p ˇ | ˇribližné polohy —
napˇríklad k rozpoznání, ve které místnosti se zaˇrízení nachází.

## Záverˇ

### Shrnutí výsledk˚u a zhodnocení

Cílem práce bylo vytvoˇrit snadno implementovatelný navigacní modul využívající technologii ˇ UWB a Wi-Fi.

Podaˇrilo se mi realizovat meˇˇrení vzdálenosti pomocí UWB, návrh a oveˇˇrení trilateracního al- ˇ goritmu (simulovaného v Pythonu), lokalizaci pomocí Wi-Fi a vytvoˇrit obecný firmware pro platformu ESP32.

Kompletní lokalizacní modul zatím nebyl otestován na fyzické mobilní platform ˇ | | | e, a tedy vý- ˇ
sledky trilaterace jsou prozatím pouze teoretické. Ostatní funkce byly oveˇˇreny a fungují dle ocekávání. ˇ

### Možnosti dalšího vývoje

Co se týce zlepšení, tak protokul pro komunikaci není perfektní, celý projekt není extra ukli- ˇ zený, a není kompletní user manual a nejaké quality of life features. ˇ

Momentální kalibrace je jen tak slepená dohromady a není ideální pro vetší zm ˇ | eny v m ˇ | eˇˇrení.

Vzhledem k tomu že jsme meli pouze 2 UWB tak jsme museli mít pouze jeden anchor, takže ˇ pˇresné nemohlo být implementováno. Architektura v kódu tam proto je, jenom to zbývá implementovat.

reálné nasazení na venkovním testováním a spoluprací s tímto projektem pro doladení jakých- ˇ koli nedostatk˚u

Projekt by se dal nasadit v autonomní robotice.

Další rozvoj projektu by se mohl zameˇˇrit na nekolik oblastí: ˇ

- Vylepšení komunikacního protokolu mezi za ˇ | ˇrízeními.
- D˚ukladnejší úklid a optimalizaci kódu, v ˇ | cetn ˇ | e vytvo ˇ | ˇrení podrobné uživatelské dokumen-
tace a pˇridání funkcí pro snadnejší použití. ˇ
- Rozšíˇrení systému na více než dva UWB moduly pro umožnení plné 3D lokalizace po- ˇ
mocí více anchor˚u. Architektura v kódu je již na tuto možnost cáste ˇ | cnˇ e p ˇ ˇripravena.
- Testování v reálných venkovních podmínkách a doladení systému na základ ˇ | e praktických ˇ
zkušeností.

Projekt má potenciál pro nasazení v oblasti autonomní robotiky, kde by mohl sloužit jako navi-
gacní modul pro vnit ˇ | ˇrní i vnejší lokalizaci. ˇ

## Seznam príloh ˇ

pˇríloha I - schéma zapojení PCB

## Seznam použité literatury a zdroj˚u informací

[1] Arduino. Arduino Documentation. 2025. URL: https://docs.arduino.cc/ (cit.
29. 04. 2025).
[2] DECAWAVE Ltd. DW1000 User Manual, Version 2.05. 2015. URL: https://thetoolchain.

com/mirror/dw1000/dw1000_user_manual_v2.05.pdf (https://thetoolchain.com/mirror/dw1000/dw1000_user_manual_v2.05.pdf) (cit. 29. 04. 2025).
[3] Espressif Systems. ESP32 Technical Reference Manual, Version 5.3. 2025. URL: https:

/ / www . espressif . com / sites / default / files / documentation /

esp32_technical_reference_manual_en.pdf (https://www.espressif.com/sites/default/files/documentation/esp32_technical_reference_manual_en.pdf) (cit. 29. 04. 2025).
[4] ISO/IEC. ISO/IEC 14882:2017: Programming Languages — C++. International Organization for Standardization. 2017.
[5] KiCad. KiCad Documentation. 2025. URL: https : / / docs . kicad . org/ (https://docs.kicad.org/) (cit.
29. 04. 2025).
[6] Python Software Foundation. Python Programming Language. 2025. URL: https://www.python.org/ (cit. 29. 04. 2025).
[7] Thotro. arduino-dw1000: A library that offers functionality to use Decawave’s DW1000

IC. 2021. URL: https : / / github . com / thotro / arduino - dw1000 (https://github.com/thotro/arduino-dw1000) (cit.
29. 04. 2025).
[8] Wikipedia. Kalman Filter. 2025. URL: https://en.wikipedia.org/wiki/Kalman_filter (https://en.wikipedia.org/wiki/Kalman_filter) (cit. 29. 04. 2025).
[9] Wikipedia. Singular Value Decomposition. 2025. URL: https://en.wikipedia.

org/wiki/Singular_value_decomposition (https://en.wikipedia.org/wiki/Singular_value_decomposition) (cit. 29. 04. 2025).
[10] Wikipedia. Trilateration. 2025. URL: https : / / en . wikipedia . org / wiki / Trilateration (https://en.wikipedia.org/wiki/Trilateration) (cit. 29. 04. 2025).

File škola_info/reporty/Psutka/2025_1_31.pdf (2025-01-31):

# RP report

Matěj Psutka

31.1.2025

Tenhle měsíc jsem vymodeloval kryt na desku, kterou udělal Franta. Je rozdělen na horní a spodní část které dohromady spojíme šroubkem. Jsou tam vývody na dvě USB-C, anténu z UWB čipu a místo na umístění baterie pod desku. Až budeme mít fyzickou desku tak ještě dodělám díry na piny a na spínač. asdasdasd

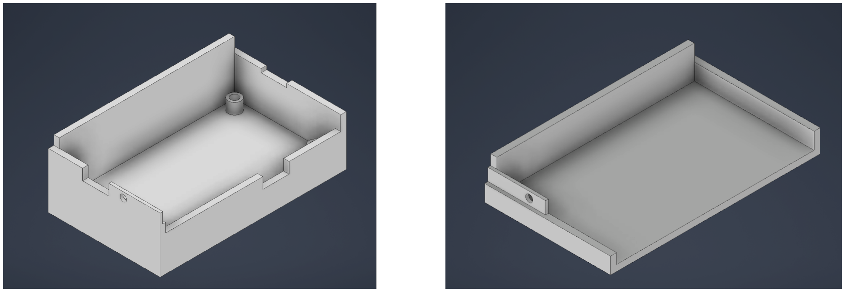
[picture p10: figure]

Spodní část | Horní část

1

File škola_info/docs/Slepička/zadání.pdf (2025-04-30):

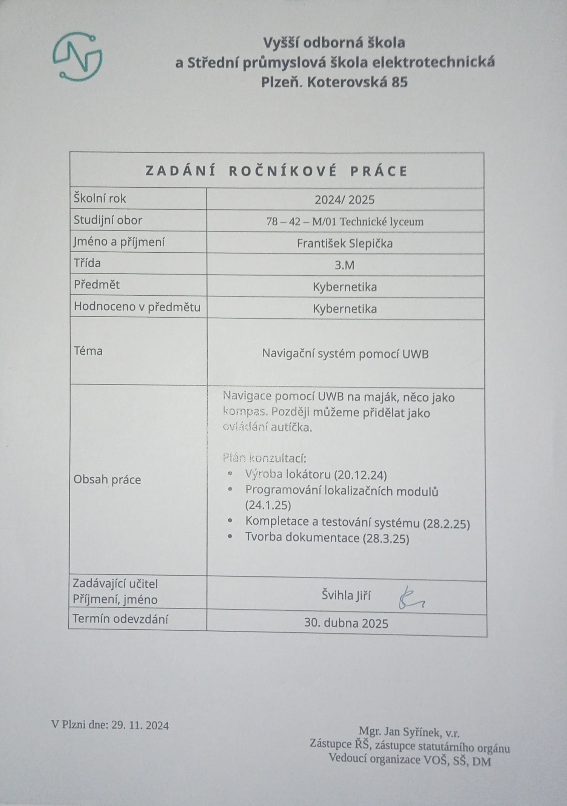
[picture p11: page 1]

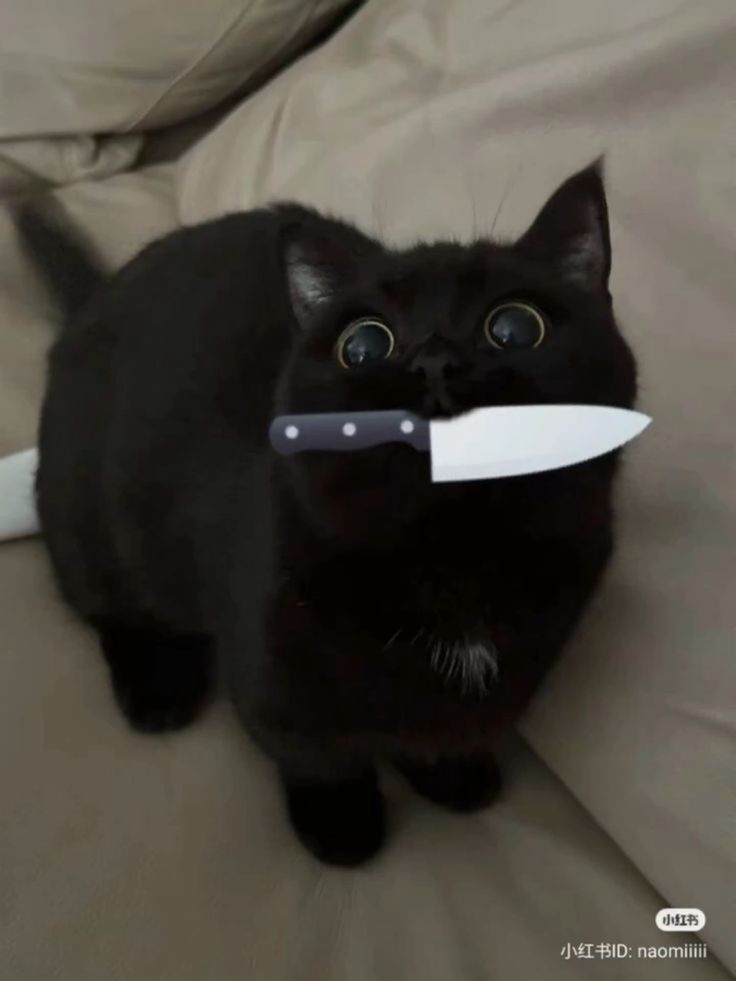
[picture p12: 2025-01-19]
PCB/kocky/nozik.jpg

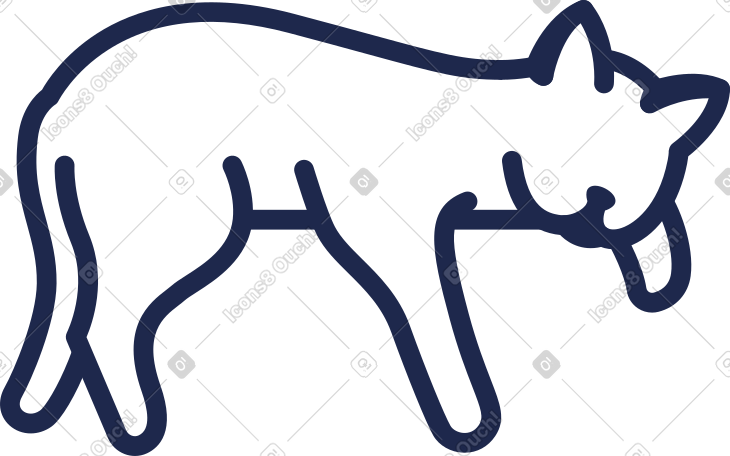
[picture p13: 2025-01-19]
PCB/kocky/eep.png

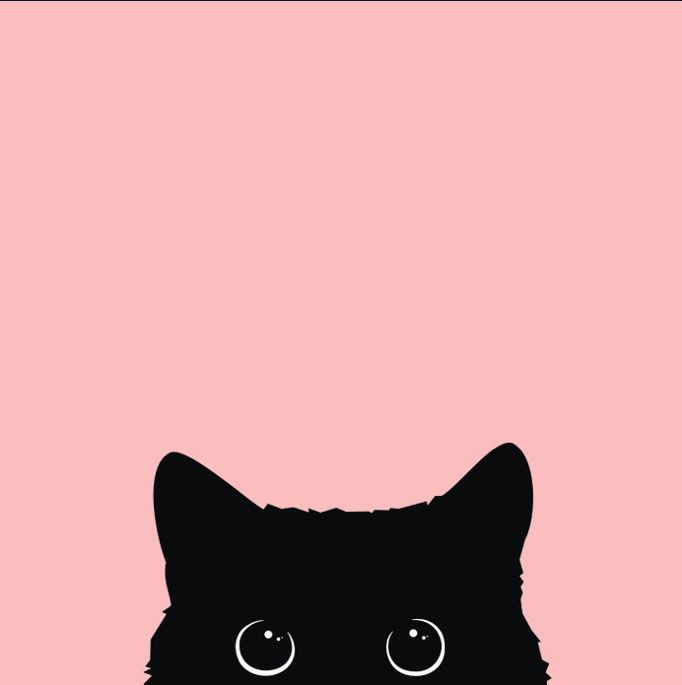
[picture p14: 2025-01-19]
PCB/kocky/kuk.jpg

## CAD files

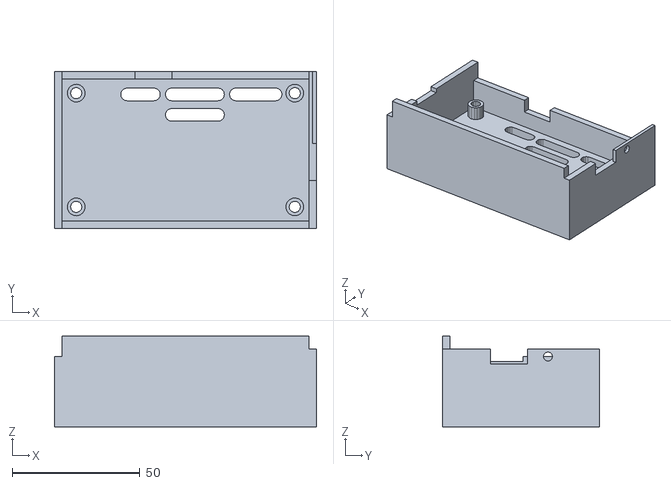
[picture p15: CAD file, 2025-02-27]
modely/krabice.stl
102.5 x 61.5 x 35.5

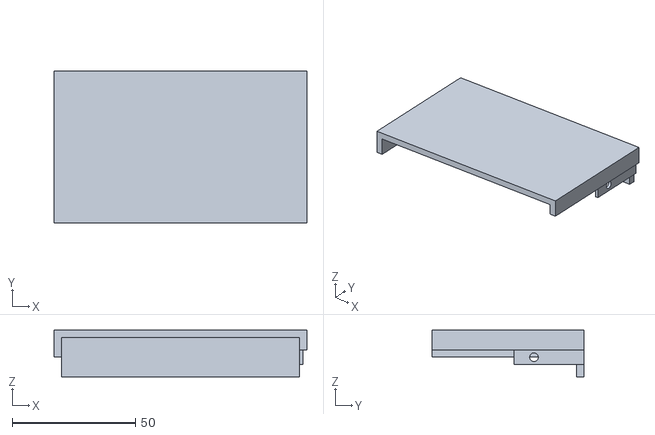
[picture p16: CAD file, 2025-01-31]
modely/krabice_vrch.stl
102.5 x 61.5 x 19.0

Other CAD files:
modely/OldVersions/krabice.0014.ipt
modely/OldVersions/krabice_vrch.0010.ipt
modely/krabice.ipt
modely/krabice_vrch.ipt

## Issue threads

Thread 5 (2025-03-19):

UWB trable

FrteenCZ, 2025-03-19:
Mám trable s SPI komunikací s DWM1000 čipem a ESP32. Při čtení z registrů se někdy data zdají být o jeden bit posunuty. Nevim jestli je to DWMkem, EPS, či zapojením, proto jsem vyzkoušel každou kombinaci:

```
zapojení, EPS, DWM

000
DW1000 Device ID: 0xBC950360
SYS_CFG Register: 0x1002400
SYS_TIME Register: 0xDED61400
MISO Pin State: 0
Written: 0xA5A5A5A5, Read: 0x4A4B4B4B

001
DW1000 Device ID: 0xDECA0130
SYS_CFG Register: 0x1200
SYS_TIME Register: 0xBDD89C00
MISO Pin State: 1
Written: 0xA5A5A5A5, Read: 0xA5A5A5A5

010
DW1000 Device ID: 0xBC950360
SYS_CFG Register: 0x1002400
SYS_TIME Register: 0xDA5BF400
MISO Pin State: 0
Written: 0xA5A5A5A5, Read: 0x4A4B4B4B

011
DW1000 Device ID: 0xBC950360
SYS_CFG Register: 0x1002400
SYS_TIME Register: 0x7D021D00
MISO Pin State: 1
Written: 0xA5A5A5A5, Read: 0x4A4B4B4B

100
DW1000 Device ID: 0xDECA0130
SYS_CFG Register: 0x1200
SYS_TIME Register: 0xC22BD600
MISO Pin State: 0
Written: 0xA5A5A5A5, Read: 0xA5A5A5A5

101 (50/50 IDK prostě je to random)
DW1000 Device ID: 0xBC950360
SYS_CFG Register: 0x1002400
SYS_TIME Register: 0x7F6B3C01
MISO Pin State: 1
Written: 0xA5A5A5A5, Read: 0x4A4B4B4B

DW1000 Device ID: 0xDECA0130
SYS_CFG Register: 0x1200
SYS_TIME Register: 0xBDD89C00
MISO Pin State: 1
Written: 0xA5A5A5A5, Read: 0xA5A5A5A5

110
DW1000 Device ID: 0xBC950360
SYS_CFG Register: 0x1002400
SYS_TIME Register: 0xF35B8500
MISO Pin State: 1
Written: 0xA5A5A5A5, Read: 0x4A4B4B4B

111
DW1000 Device ID: 0xBC950360
SYS_CFG Register: 0x1002400
SYS_TIME Register: 0x63543C01
MISO Pin State: 1
Written: 0xA5A5A5A5, Read: 0x4A4B4B4B
```

správně jsou pouze ty které přečetli: "DW1000 Device ID: 0xDECA0130", jak vyplývá z datasheetu výrobce (https://thetoolchain.com/mirror/dw1000/dw1000_user_manual_v2.05.pdf - str.65)

Tyto stavy jsou konzistentní pro každý restart, ale minimálně u jednoho (101) byla cca 50% šance jestli to bude dobře či špatně po vypojení a zapojení USB

používám při tom tento kód (o jeho správnosti velmi pochybuji, protože je to poprvé co dělám s SPI, takže většina je GPT):
```cpp
#include <SPI.h>
#include <Arduino.h>

#define DW_CS_PIN 15   // Chip Select (CS)
#define DW_MOSI_PIN 13 // Master Out Slave In (MOSI)
#define DW_MISO_PIN 12 // Master In Slave Out (MISO)
#define DW_SCLK_PIN 14 // Serial Clock (SCLK)
#define DW_IRQ_PIN 16  // Interrupt Request (IRQ, optional)
#define DW_RST_PIN 17  // Reset (RST, optional)

void resetDW1000_Hardware() {
    pinMode(DW_RST_PIN, OUTPUT);
    digitalWrite(DW_RST_PIN, LOW);  // Hold RSTn LOW to reset
    delay(10);                       // Wait 10ms
    digitalWrite(DW_RST_PIN, HIGH); // Release reset
    delay(10);                       // Allow time to stabilize
  }

uint32_t readRegister32(uint8_t reg)
{
    uint32_t value = 0;
    digitalWrite(DW_CS_PIN, LOW);

    delayMicroseconds(10); // Small delay before SPI transfer

    SPI.transfer(reg);

    for (int i = 0; i < 4; i++)
    {
        value |= ((uint32_t)SPI.transfer(0x00)) << (8 * i);
    }

    digitalWrite(DW_CS_PIN, HIGH);
    return value;
}

void writeRegister32(uint8_t reg, uint32_t value)
{
    digitalWrite(DW_CS_PIN, LOW);

    delayMicroseconds(10); // Small delay before SPI transfer

    SPI.transfer(reg | 0x80); // Set write bit (bit 7 = 1)

    for (int i = 0; i < 4; i++)
    {
        SPI.transfer((value >> (8 * i)) & 0xFF); // Send LSB first
    }

    digitalWrite(DW_CS_PIN, HIGH);
}

void testWriteRead()
{
    writeRegister32(0x1F, 0xA5A5A5A5);        // Write test value
    uint32_t readBack = readRegister32(0x1F); // Read back

    Serial.print("Written: 0xA5A5A5A5, Read: 0x");
    Serial.println(readBack, HEX);
}

void testMISO()
{
    pinMode(DW_CS_PIN, OUTPUT);
    digitalWrite(DW_CS_PIN, LOW); // Enable DW1000
    delay(10);

    pinMode(DW_MISO_PIN, INPUT);
    Serial.print("MISO Pin State: ");
    Serial.println(digitalRead(DW_MISO_PIN)); // Should be LOW or HIGH, not floating

    digitalWrite(DW_CS_PIN, HIGH); // Disable DW1000
}

void writeRegister8(uint8_t reg, uint8_t value)
{
    digitalWrite(DW_CS_PIN, LOW);

    // Send write command (bit 7 set to 1 for write operation)
    SPI.transfer(reg | 0x80);
    SPI.transfer(value);

    digitalWrite(DW_CS_PIN, HIGH);
}

void resetDW1000()
{
    digitalWrite(DW_CS_PIN, LOW);
    delay(10);
    digitalWrite(DW_CS_PIN, HIGH);
    delay(10);
    // Perform a soft reset
    writeRegister8(0x0D, 0x01); // Set SOFTRESET bit in SYS_CTRL
    delay(10);
}

void setup()
{
    Serial.begin(115200);

    resetDW1000_Hardware();

    // Initialize SPI with custom pins
    SPI.begin(DW_SCLK_PIN, DW_MISO_PIN, DW_MOSI_PIN, DW_CS_PIN);

    SPI.beginTransaction(SPISettings(100000, MSBFIRST, SPI_MODE0));

    pinMode(DW_CS_PIN, OUTPUT);
    digitalWrite(DW_CS_PIN, HIGH);

    pinMode(DW_IRQ_PIN, INPUT); // Set IRQ pin as input

    // resetDW1000();

    // Read the Device ID register at 0x00
    uint32_t devID = readRegister32(0x00);
    Serial.print("DW1000 Device ID: 0x");
    Serial.println(devID, HEX);

    uint32_t sysConfig = readRegister32(0x04);
    Serial.print("SYS_CFG Register: 0x");
    Serial.println(sysConfig, HEX);

    uint32_t sysTime = readRegister32(0x06);
    Serial.print("SYS_TIME Register: 0x");
    Serial.println(sysTime, HEX);

    testMISO();

    testWriteRead();
}

void loop()
{
    // Your code here
}
```

A vytvořil jsem toto zapojení + PCB:

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

toto zapojení jsem několikrát na nepájivých polích zkontroloval, avšak má retardace dosahuje nebeských výšin, takže ani tomu nevěřím. Máme už PCB takže až se to na to zapájí tak by *nemělo* být špatně.
Ještě vyzkouším párkrát různé kombinace a podívám se jestli mám správně nastavený SPI.

bublinak, 2025-04-06:
Přines to do školy a stěžuj si ať se ti věnuju tohle z domova nedám. Přidal bych delay po restartu DWM pro začátek
```cpp
Serial.begin(115200);

resetDW1000_Hardware();
delay(100); // At least 100 miliseconds to properly boot the device

// Initialize SPI with custom pins
SPI.begin(DW_SCLK_PIN, DW_MISO_PIN, DW_MOSI_PIN, DW_CS_PIN);
```

bublinak, 2025-04-10:
Nazdárek, zkus tuhle knihovnu: [https://github.com/thotro/arduino-dw1000/tree/master](https://github.com/thotro/arduino-dw1000/tree/master)

Je sice už lehce přesluhující, ale čip rozjela.
> Poznámka: V knihovně (DV1000.cpp) smaž řádky 172-174 (`SPI.usingInterrupt(digitalPinToInterrupt(irq));`). Tuhle funkcionalitu už ESP-IDF nemá.

Taky máš chybu v zapojení - máš prohozený IRQ a RST pin. Stačilo prohodit v nastavení

Kód co to rozjel:
```cpp
#include <SPI.h>
#include <Arduino.h>

#define DW_CS_PIN 15   // Chip Select (CS)
#define DW_MOSI_PIN 13 // Master Out Slave In (MOSI)
#define DW_MISO_PIN 12 // Master In Slave Out (MISO)
#define DW_SCLK_PIN 14 // Serial Clock (SCLK)
#define DW_IRQ_PIN 17  // Interrupt Request (IRQ, optional)
#define DW_RST_PIN 16  // Reset (RST, optional)

#include <DW1000.h>

void setup() {
	// Initialize Serial for debugging
	Serial.begin(115200);
	Serial.println("DW1000 Device ID Reader");

	// Initialize SPI
	SPI.begin(DW_SCLK_PIN, DW_MISO_PIN, DW_MOSI_PIN, DW_CS_PIN);

	// Initialize DW1000 module
	DW1000.begin(DW_IRQ_PIN, DW_RST_PIN);
	DW1000.select(DW_CS_PIN);
	Serial.println("DW1000 initialized...");

	// Configure DW1000 with basic settings
	DW1000.newConfiguration();
	DW1000.setDeviceAddress(5);
	DW1000.setNetworkId(10);
	DW1000.commitConfiguration();
	Serial.println("Configuration committed...");

	// Wait for a moment
	delay(1000);
}

void loop() {
	// Print device information
	char msg[128];

	DW1000.getPrintableDeviceIdentifier(msg);
	Serial.print("Device ID: ");
	Serial.println(msg);

	DW1000.getPrintableExtendedUniqueIdentifier(msg);
	Serial.print("Unique ID: ");
	Serial.println(msg);

	DW1000.getPrintableNetworkIdAndShortAddress(msg);
	Serial.print("Network ID & Device Address: ");
	Serial.println(msg);

	DW1000.getPrintableDeviceMode(msg);
	Serial.print("Device mode: ");
	Serial.println(msg);

	// Wait between readings
	delay(5000);
}
```

bublinak, 2025-04-10:
V platformiu je ta knihovna dostupná jako `DW1000 by Thomas Trojer`

Closed 2025-04-10.

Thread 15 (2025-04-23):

UWB calibration

FrteenCZ, 2025-04-23:
Je to broken :,(
bude třeba synchroní kalibrace na obou zařízeních

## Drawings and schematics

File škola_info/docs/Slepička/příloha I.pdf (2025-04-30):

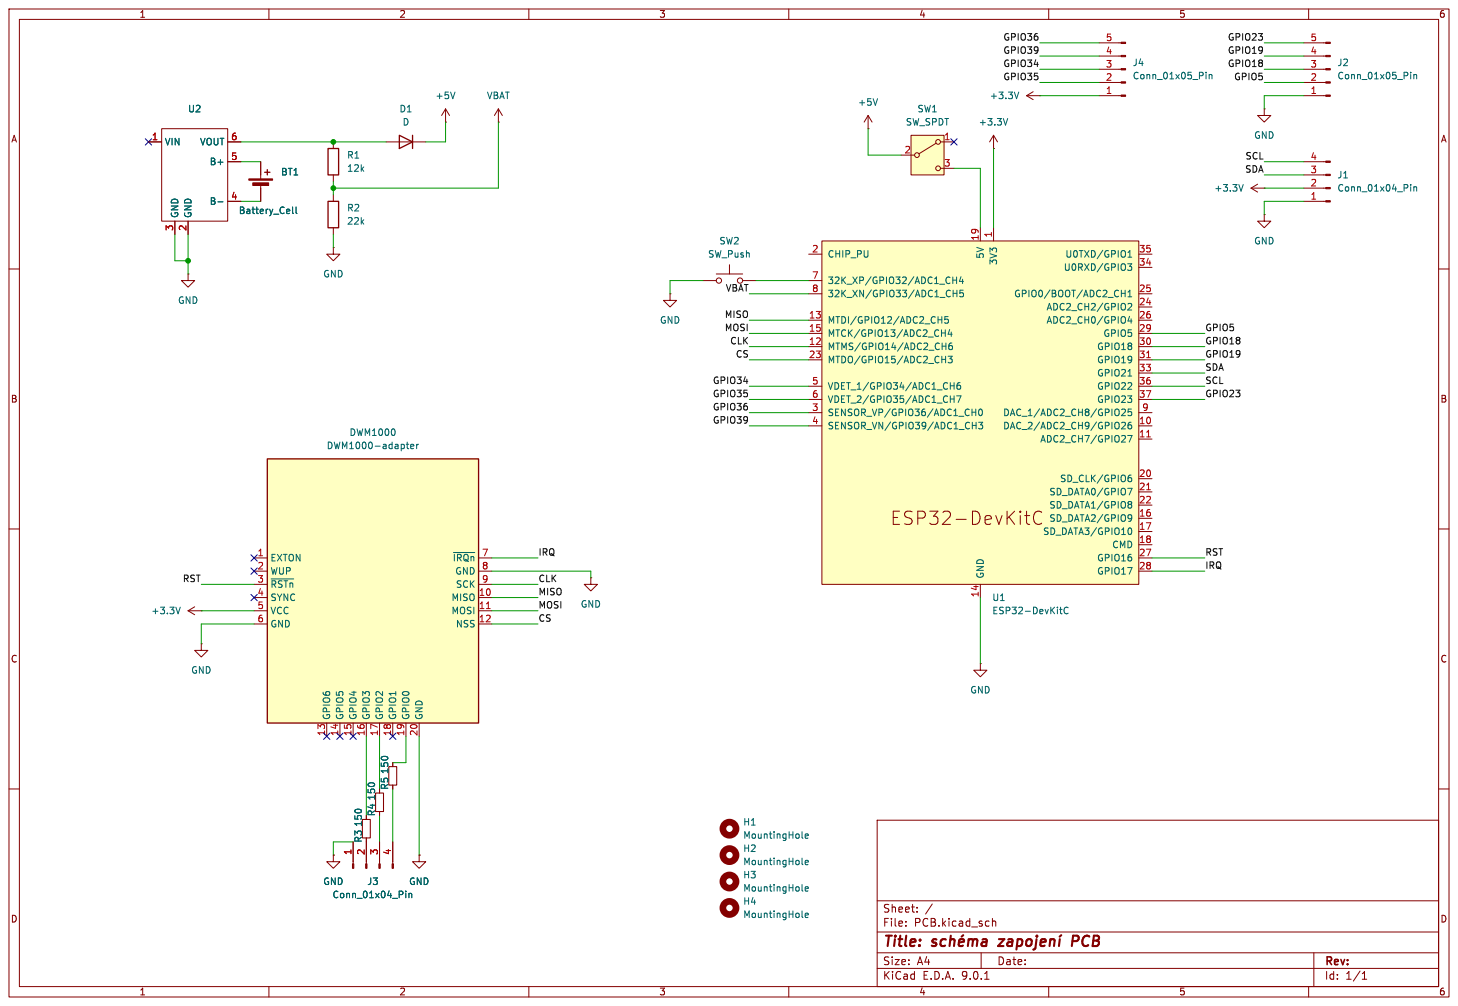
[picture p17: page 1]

H1 MountingHole H4 MountingHole H2 MountingHole H3 MountingHole R5 150 R4 150 R3 150

File: PCB.kicad_sch Sheet: /
Id: 1/1 Title: þÿschéma þÿzapojení PCB

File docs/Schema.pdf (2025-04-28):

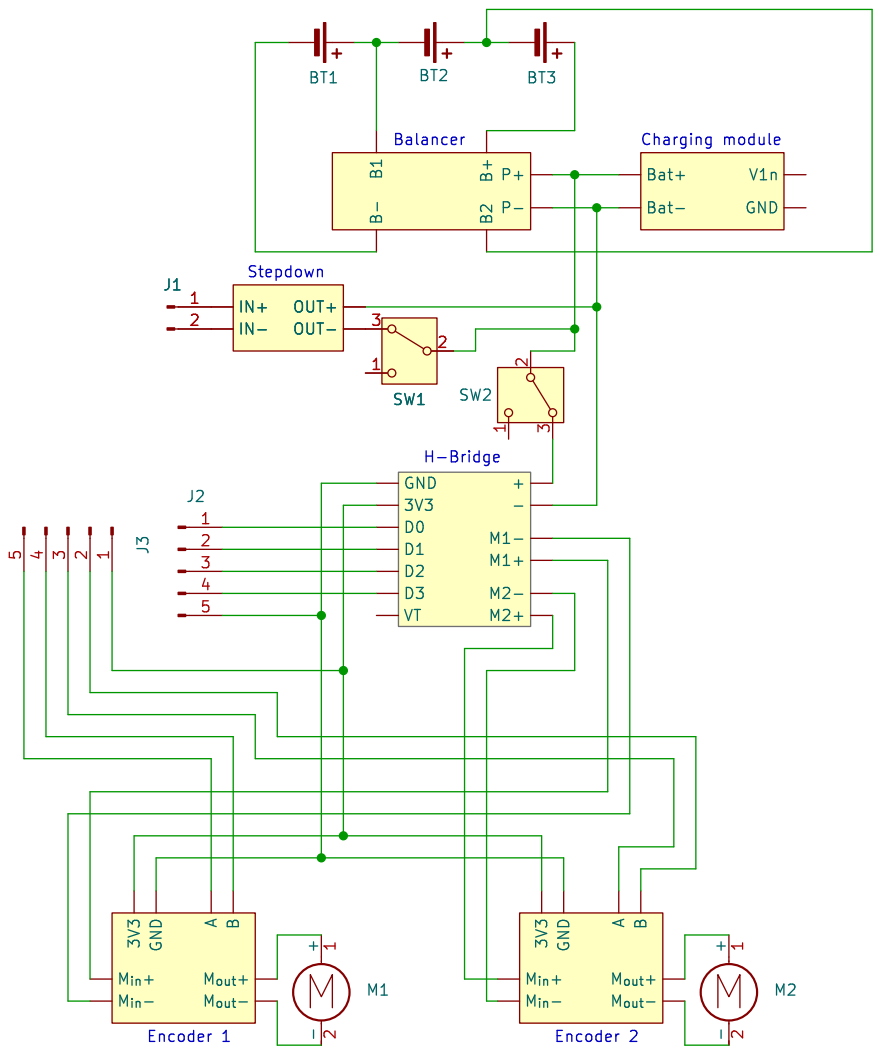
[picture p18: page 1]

Id: 1/1 Title: Auto þÿschéma

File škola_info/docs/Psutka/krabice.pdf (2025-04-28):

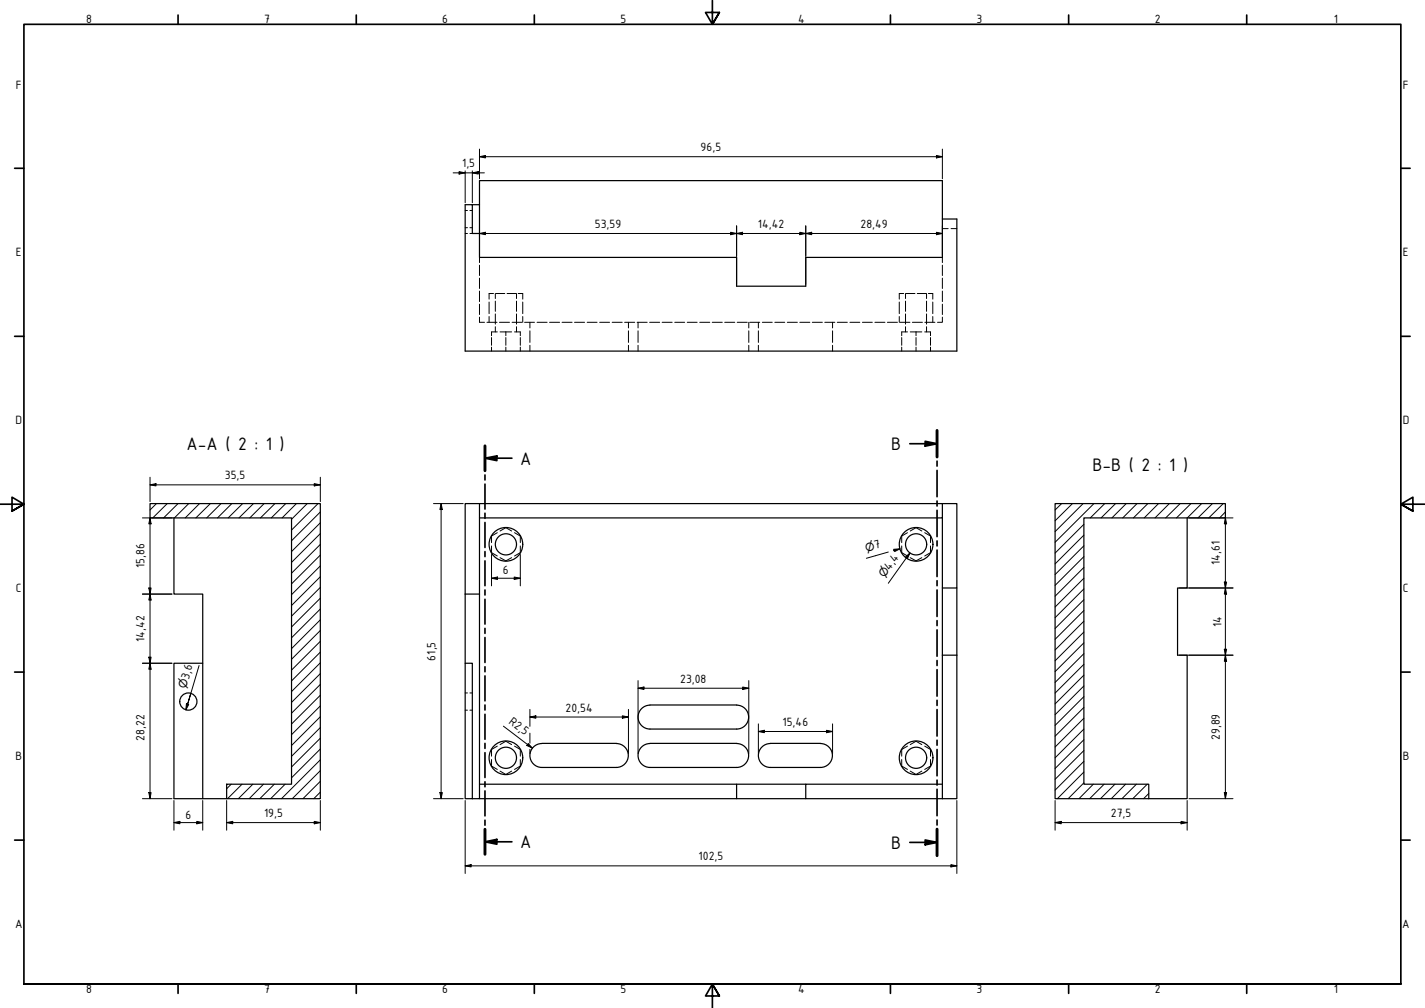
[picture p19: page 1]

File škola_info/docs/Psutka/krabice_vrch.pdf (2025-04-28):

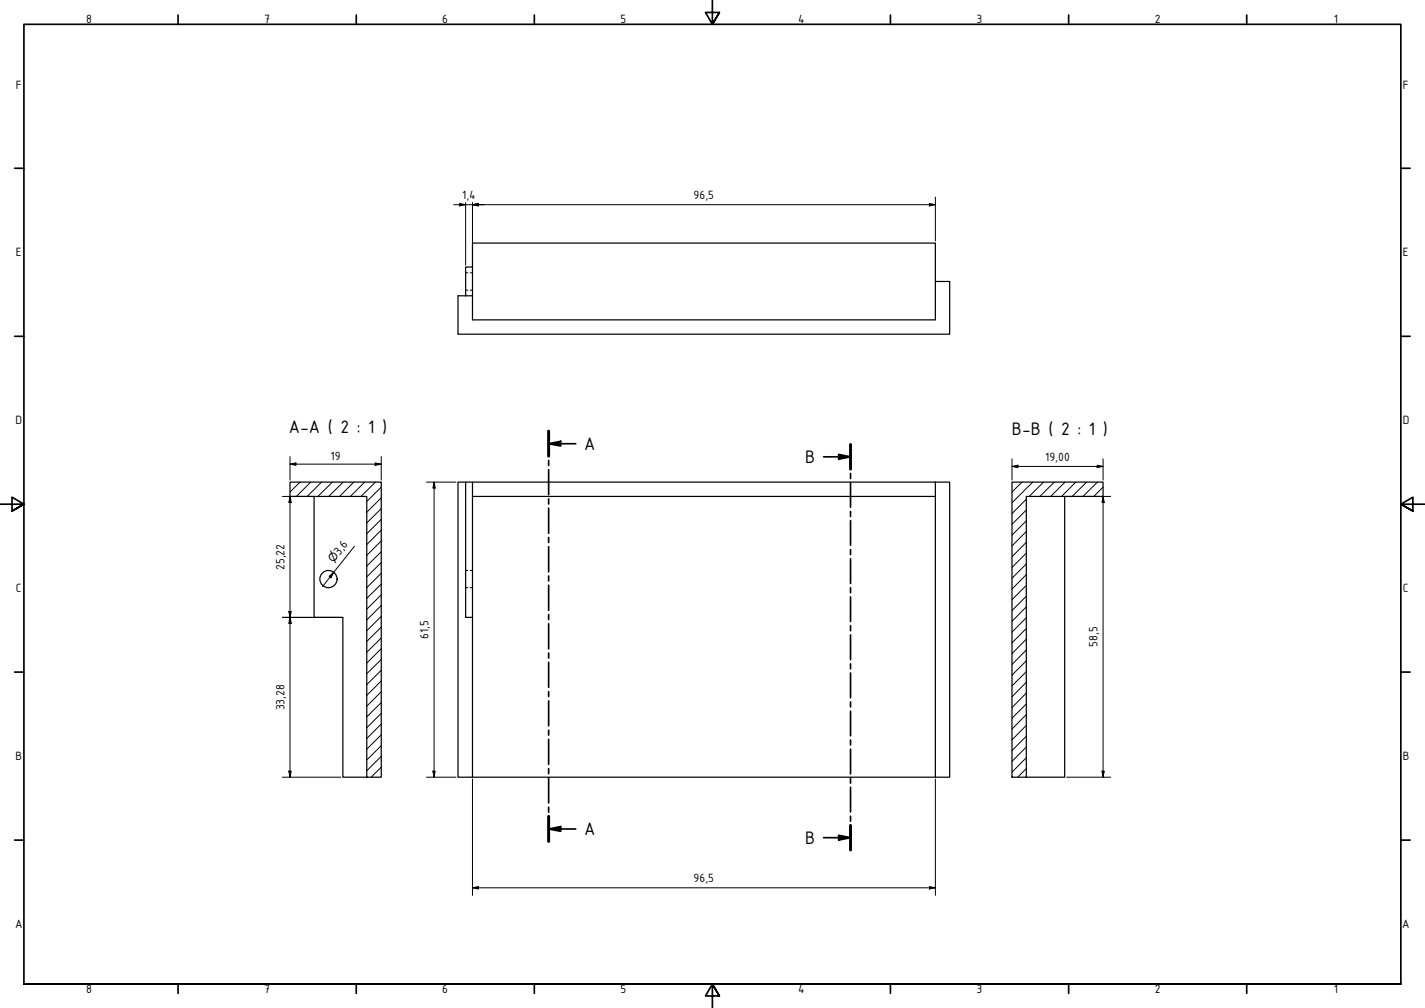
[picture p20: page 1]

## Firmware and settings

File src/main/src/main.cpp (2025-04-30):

#include "main.h"

String onboardledState = "OFF";

// Create WiFi server on port 80
WebServer server(80);

void handleRoot()
{
    File file = SPIFFS.open("/index.html", "r");
    if (!file)
    {
        server.send(500, "text/plain", "Failed to open file");
        return;
    }
    String html = file.readString();
    file.close();
    server.send(200, "text/html", html);
}

void handleCss()
{
    File file = SPIFFS.open("/style.css", "r");
    if (!file)
    {
        server.send(500, "text/plain", "Failed to open file");
        return;
    }
    String css = file.readString();
    file.close();
    server.send(200, "text/css", css);
}

void handleNotFound()
{
    Serial.print("Unhandled request: ");
    Serial.println(server.uri()); // Print the requested URL
    server.send(404, "text/plain", "Not Found");
}

void setup()
{
    Serial.begin(115200);

    // Set onboard LED pin as output
    pinMode(onboardledPin, OUTPUT);

    // Initialize SPIFFS
    if (!SPIFFS.begin(true))
    { // true -> format if failed
        Serial.println("SPIFFS Mount Failed");
        return;
    }
    Serial.println("SPIFFS Mounted Successfully");

    // connect_to_wifi(1, 5, true, "SSID", "PASSWORD");
    if (WiFi.status() != WL_CONNECTED)
    {
        connect_to_wifi();
        if (WiFi.status() != WL_CONNECTED)
        {
            start_AP("ESP32-AP", "12345678");
        }
    }

    LED_test_setup();
    wifi_connection_setup();
    wifi_location_setup();
    UWB_setup();

    // Setup routes
    server.on("/", handleRoot);
    server.on("/style.css", handleCss);

    server.onNotFound(handleNotFound);

    server.begin();

    onboardledState = "on";
    digitalWrite(onboardledPin, HIGH);
}

void loop()
{
    // Handle serial input
    handleSerialInput();

    server.handleClient();
    UWB_loop();
}

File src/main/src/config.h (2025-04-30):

#ifndef CONFIG_H
#define CONFIG_H

const int onboardledPin = 2;


// Define the pin configuration for DWM1000
#define UWB_PIN_SPI_MISO  12    // SPI MISO
#define UWB_PIN_SPI_MOSI  13    // SPI MOSI
#define UWB_PIN_SPI_SCK   14    // SPI Clock
#define UWB_PIN_SPI_SS    15    // Chip Select
#define UWB_PIN_SPI_RST   16    // Reset
#define UWB_PIN_SPI_IRQ   17    // Interrupt

// Define the default antenna delay
#define DEFAULT_ANTENNA_DELAY 16150 // Default antenna delay in picoseconds

#endif

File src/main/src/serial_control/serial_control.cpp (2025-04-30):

#include "serial_control.h"

bool is2D = true;     // Default assumption
bool modeSet = false; // Flag to lock mode after first input

trilateration trilat;

void handleSerialInput()
{
    if (Serial.available())
    {
        String input = Serial.readStringUntil('\n');
        // Serial.println("Received: " + input);

        // LED control
        if (input == "LED ON")
        {
            digitalWrite(onboardledPin, HIGH);
            Serial.println("LED is ON");
        }
        else if (input == "LED OFF")
        {
            digitalWrite(onboardledPin, LOW);
            Serial.println("LED is OFF");
        }

        // Handle trilateration input
        else if (input.startsWith("cords["))
        {
            float x, y, z, d;
            // First, determine if the input is 2D or 3D
            if (!modeSet && sscanf(input.c_str(), "cords[%f,%f,%f],%f", &x, &y, &z, &d) == 4 ||
                sscanf(input.c_str(), "cords[%f,%f,%f]", &x, &y, &z) == 3)
            {
                is2D = false;
                modeSet = true;
                Serial.println("3D mode set.");
                trilat = trilateration(3); // Initialize 3D trilateration
            }
            else if (!modeSet && sscanf(input.c_str(), "cords[%f,%f],%f", &x, &y, &d) == 3 ||
                     sscanf(input.c_str(), "cords[%f,%f]", &x, &y) == 2)
            {
                is2D = true;
                modeSet = true;
                Serial.println("2D mode set.");
                trilat = trilateration(2); // Initialize 2D trilateration
            }

            // After mode is determined, parse using the right pattern
            if (sscanf(input.c_str(), "cords[%f,%f,%f],%f", &x, &y, &z, &d) == 4 ||
                sscanf(input.c_str(), "cords[%f,%f,%f]", &x, &y, &z) == 3)
            {
                if (sscanf(input.c_str(), "cords[%f,%f,%f]", &x, &y, &z) == 3) {
                    d = distance; // Use the own measured distance
                }
                if (is2D)
                {
                    Serial.println("Warning: Input is 3D but mode is set to 2D. Ignoring z-coordinate.");
                    trilat.update({x, y, d});
                }
                else
                {
                    trilat.update({x, y, z, d});
                }
            }
            else if (sscanf(input.c_str(), "cords[%f,%f],%f", &x, &y, &d) == 3 ||
                     sscanf(input.c_str(), "cords[%f,%f]", &x, &y) == 2)
            {
                if (sscanf(input.c_str(), "cords[%f,%f]", &x, &y) == 2) {
                    d = distance; // Use the own measured distance
                }
                if (!is2D)
                {
                    Serial.println("Warning: Input is 2D but mode is set to 3D. Providing default z=0.");
                    z = 0;
                    trilat.update({x, y, z, d});
                }
                else
                {
                    trilat.update({x, y, d});
                }
            }
            else
            {
                Serial.println("Invalid input format. Expected format: cords[x,y,z],d or cords[x,y],d or cords[x,y,z] or cords[x,y]");
            }
        }
        else if (input == "getState")
        {
            Matrix state = trilat.getState();
            Serial.print("Current state: ");
            for (int i = 0; i < state.rows(); i++)
            {
                for (int j = 0; j < state.cols(); j++)
                {
                    Serial.print(state[i][j]);
                    Serial.print(" ");
                }
                Serial.println();
            }
        }
        else if (input == "printBuffer")
        {
            trilat.printBuffer();
        }

        // WiFi control
        else if (input == "WiFi auto")
        {
            connect_to_wifi();
        }
        else if (input == "WiFi AP")
        {
            start_AP("ESP32-AP", "12345678");
        }
        else if (input.startsWith("WiFi connect to ")) // Example input: "WiFi connect to MySSID MyPassword"
        {
            String ssid = input.substring(16, input.indexOf(' ', 16));
            String password = input.substring(input.indexOf(' ', 16) + 1);
            connect_to_wifi(1, 5, ssid.c_str(), password.c_str());
        }
        else if (input == "WiFi scan")
        {
            scan_wifi();
        }

        // WiFi location control
        else if (input == "WiFi location")
        {
            scan_wifi();

            // Load stored locations
            File file = SPIFFS.open("/networks.json", "r");
            if (!file)
            {
                Serial.println("Failed to open file for reading");
                return;
            }

            // Read file into a string
            String content = file.readString();
            file.close();

            // Parse the string into a JSON document
            JsonDocument doc;
            DeserializationError error = deserializeJson(doc, content);
            if (error)
            {
                Serial.print("Failed to parse JSON: ");
                Serial.println(error.c_str());
                return;
            }

            // Extract the JSON object
            JsonObject root = doc.as<JsonObject>();

            // Find the matching location
            findMatchingLocation(root);
            Serial.println(bestMatch.name);
            Serial.printf("Location: %f, %f, %f\n", bestMatch.location[0], bestMatch.location[1], bestMatch.location[2]);
        }

        // UWB control
        else if (input == "UWB start")
        {
            Serial.println("Starting UWB...");
            UWB_start();
        }
        else if (input == "UWB stop")
        {
            Serial.println("Stopping UWB...");
            UWB_stop();
        }
        else if (input == "UWB status")
        {
            Serial.println("UWB status: ...");
            if (isRanging)
            {
                Serial.println("Ranging is active");
            }
            if (isAnchor)
            {
                Serial.println("Device is in anchor mode");
            }
            else
            {
                Serial.println("Device is in tag mode");
            }
            Serial.print("Distance: ");
            Serial.println(distance);
        }
        else if (input == "UWB switch mode")
        {
            Serial.println("Switching UWB mode...");
            UWB_switchMode();
        }
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

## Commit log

2025-01-18 PCB schematic (WIP)
    [PCB.kicad_pcb, PCB.kicad_sch]
2025-01-18 PCB progress
    [PCB.kicad_pcb, PCB.kicad_sch]
2025-01-19 PCB is finished, but esp is the wrong way :(
    [PCB.kicad_pcb, PCB.kicad_sch]
2025-01-19 PCB redesign
    [PCB.kicad_pcb, PCB.kicad_sch]
2025-01-21 PCB update
    [PCB.kicad_pcb]
2025-01-24 repaired the size of an esp
    [PCB.kicad_pcb]
2025-01-29 rewrote wifi-scan from C to arduino
2025-01-31 added model folder, renamed school_project
    [krabice.ipt, krabice.stl, krabice_vrch.ipt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]
2025-02-05 added some basic control and status page controling onboard LED
2025-02-15 seperated out LED_test to its own file
2025-02-16 web page for LED_test and wifi_connection added
2025-02-16 fix the scan_wifi function
    [wifi.cpp]
2025-02-19 added pins for motor encoders
    [PCB.kicad_pcb, PCB.kicad_sch]
2025-02-19 deleting status pag. It's all written in main under LED_test now.
2025-02-22 added ability to send strings in LED_test
2025-02-22 fix: correct RSSI value handling in WiFi scanning
    [wifi.cpp]
2025-02-25 new header for encoders, adjusted resitor values
    [PCB.kicad_pcb, PCB.kicad_sch]
2025-02-25 new models with holes for pogo pins
    [krabice.ipt, krabice.stl]
2025-02-26 better button animations
2025-02-27 fix: fixed wrong wiring of the UWB
    [PCB.kicad_pcb, PCB.kicad_sch]
2025-02-28 added holes for pins to models
    [krabice.0012.ipt, krabice.ipt, krabice_vrch.0007.ipt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]
2025-03-05 refactor: enhance Wi-Fi scanning functionality with LED feedback and modularize scanning process
2025-03-05 feat: add UWB module with setup and loop functions for device ranging
2025-03-05 refactor: update platformio.ini to support multiple ESP32 environments with distinct upload and monitor ports and modes for UWB
2025-03-12 feat: add matrix class with multiplication and print functionality
2025-03-14 feat: implement matrix inversion with error handling for non-square and singular matrices
    [matrix.cpp]
2025-03-14 feat: implement Kalman Filter class for state estimation and prediction
2025-03-15 fix: update inverse method to return empty matrix for non-square and singular matrices
    [matrix.cpp]
2025-03-15 fix: add const qualifier to qrDecomposition method in Matrix class
    [matrix.cpp]
2025-03-23 refactor: remove debug print statements from solveLeastSquares function
2025-03-23 refactor: improve code readability and documentation in least squares and Kalman filter implementations
2025-03-25 refactor: remove debug print statements from qrDecomposition method in Matrix class
2025-03-28 feat: add computeEquations function for least squares problem formulation
    [leastSquare.cpp]
2025-03-28 feat: enhance Matrix class with error handling and some cleanup
    [matrix.cpp]
2025-03-28 feat: improve error handling in Matrix class by returning appropriate fallback matrices
    [matrix.cpp]
2025-03-28 feat: add validation checks and error handling in solveLeastSquares function
    [leastSquare.cpp]
2025-03-28 feat: enhance error messages in Matrix class for dimension mismatch in addition and subtraction
    [matrix.cpp]
2025-03-28 feat: add computeCentroid function to calculate the centroid of a set of coordinates with error handling for empty matrices
    [leastSquare.cpp]
2025-03-29 fix: correct normal vector assignment in findPlane function
    [leastSquare.cpp]
2025-03-29 fix: improve error messages in solveLeastSquares function for better clarity
    [leastSquare.cpp]
2025-03-30 fix: enhance input validation in reconstruct3D function for better error handling
    [leastSquare.cpp]
2025-03-30 fix: remove unnecessary centroid validation from reconstruct3D function
    [leastSquare.cpp]
2025-04-03 feat: add printBuffer method to display buffer contents in trilateration class
2025-04-06 fix: SVD now actually works
    [leastSquare.cpp]
2025-04-17 feat: UWB finally works, meassures distances, runtime mode switch
2025-04-17 fix: swap UWB_PIN_SPI_IRQ and UWB_PIN_SPI_RST definitions for correct pin mapping
    [config.h]
2025-04-17 feat: add UWB Control Panel HTML interface for managing ranging and mode switching
2025-04-17 feat: add HTML endpoints for LED test, Wi-Fi connection, and location handling
2025-04-18 feat: add UWB calibration functionality
2025-04-18 feat: add calibration feature to UWB Control Panel HTML interface
2025-04-18 fix: correct password key in Wi-Fi credential handling
    [wifi.cpp]
2025-04-18 fix: adjust delay parameters and improve calibration logging in UWB module
    [UWB.cpp]
2025-04-21 feat: implement preferences for antenna delay and ranging state management
2025-04-22 Added schematic for the car
    [schema.kicad_pcb, schema.kicad_sch]
2025-04-22 Updated models
    [krabice.0012.ipt, krabice.0013.ipt, krabice.ipt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]
2025-04-28 my documentation
    [krabice.0013.ipt, krabice.0014.ipt, krabice.ipt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]
2025-04-30 feat: enhance trilateration logic to support dynamic 2D/3D mode switching
2025-04-30 feat: add UWB simulation logic with ESP32 communication and animation
2025-04-30 refactor: reorganize code structure and enhance WiFi handling with new routing and error handling
    [main.cpp]
2025-04-30 feat: add UWB start and stop functions, rename switchMode for clarity
2025-04-30 fix: fixed UWB functions to their new names and reduce redundancy
    [UWB.cpp]
2025-04-30 feat: add PCB design document
2025-07-02 feat: enabled inputing multiple points at the same times and deleted uneccessary Serial prints
2025-07-04 feat: add printJSON method to output matrix in JSON format
2025-07-04 feat: add JSON output for trilateration solution and Kalman filter state
